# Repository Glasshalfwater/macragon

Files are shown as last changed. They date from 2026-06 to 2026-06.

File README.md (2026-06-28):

# Macragon

### Hexagonal macropad powered by a Waveshare 2040-zero with multiple keyboard layers, USB-C connectivity, RGB LEDs, and planned voice keyboard functionality.

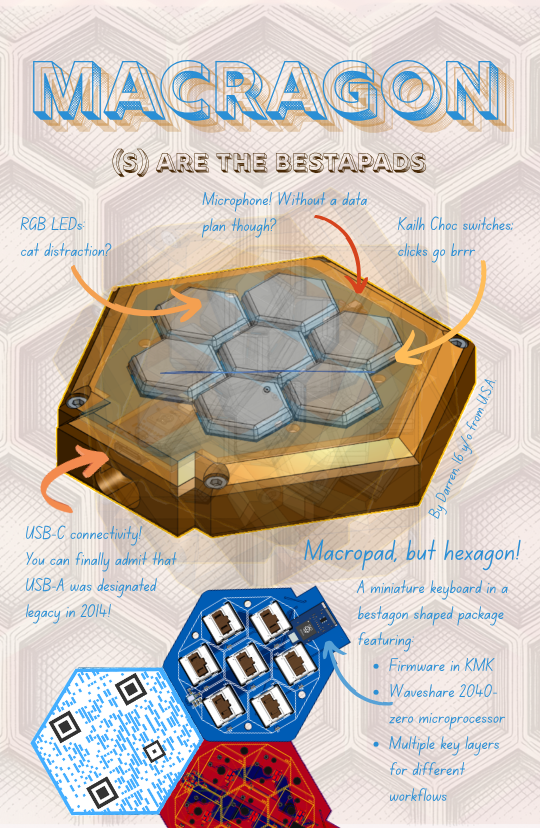
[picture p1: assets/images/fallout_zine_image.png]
zine poster


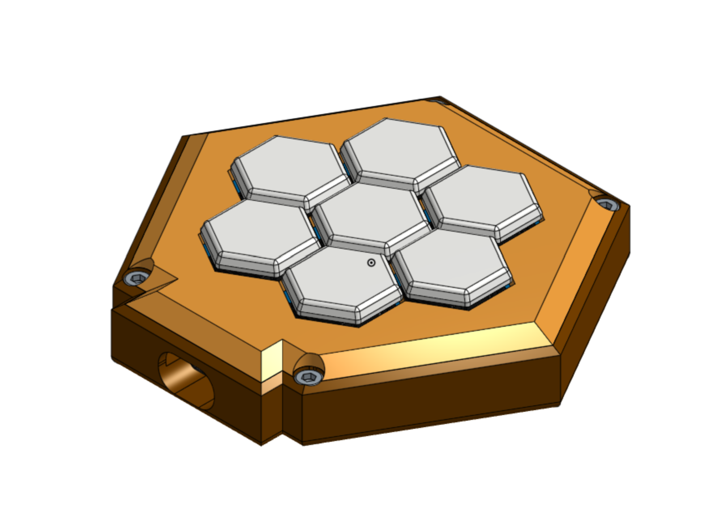
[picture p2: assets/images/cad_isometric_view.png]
Onshape link (https://cvilleschools.onshape.com/documents/f18c9192e8883840eb23ee3e/w/cfee4e89906b8c2d7cd90130/e/c8d4c75ffcaf924e3f809773)


## Origins:
To be honest, my main motivation behind this project is mostly laziness :>. Long story short, my engineering class's keyboards are a bit annoying. To use them properly, one has to actually sit in their chair very close to one's respective desk (it's more tiring than it sounds after an hour and a half). The chair arms are too far apart to support the keyboard away from the desk, and the rubber pads on the bottom of the keyboard mean that dust and debris will collect on your pants if the keyboard is in your lap. So, what I wanted to do is to have a little mic I could carry around that functioned as a voice keyboard, so I could actually slouch in my chair comfortably at a distance. That, combined with me seeing a lot of other Hackclub projects being macropads, meant I decided to make a fusion between the two. Ideally, the goal was to learn how to read and make schematics, PCB design, and improve my coding skills. The (farfetched) dream would be to have a voice keyboard that could recognize CAD commands while also having buttons for manual functions. Unfortunately, implementing a voice keyboard that plugs in as a USB audio device was harder than I expected in Python (I had decided to use KMK instead of QMK), compounded by my lack of experience in Python and with USB audio communication. As such, it has been left off until v2 of the macragon. However, the macropad keys still work, and as a bonus they have RGB LEDs. Additionally, the hardware for the microphone is on the PCB, and QMK supports the microprocessor, etc., so adding a voice keyboard will simply be a firmware update.

Another segment of motivation is just my fingers getting mad at me after I'd been creating hexagons and other repetitive tasks in Onshape without convienient keybinds for two hours a day for a week. (Yeah, I probably should have just unbound some other keybind I wasn't using, but macropads are cooler.)

On the other hand, choosing the shape of my macropad was [easy](https://www.youtube.com/watch?v=thOifuHs6eY).

## Wiring Schematic 
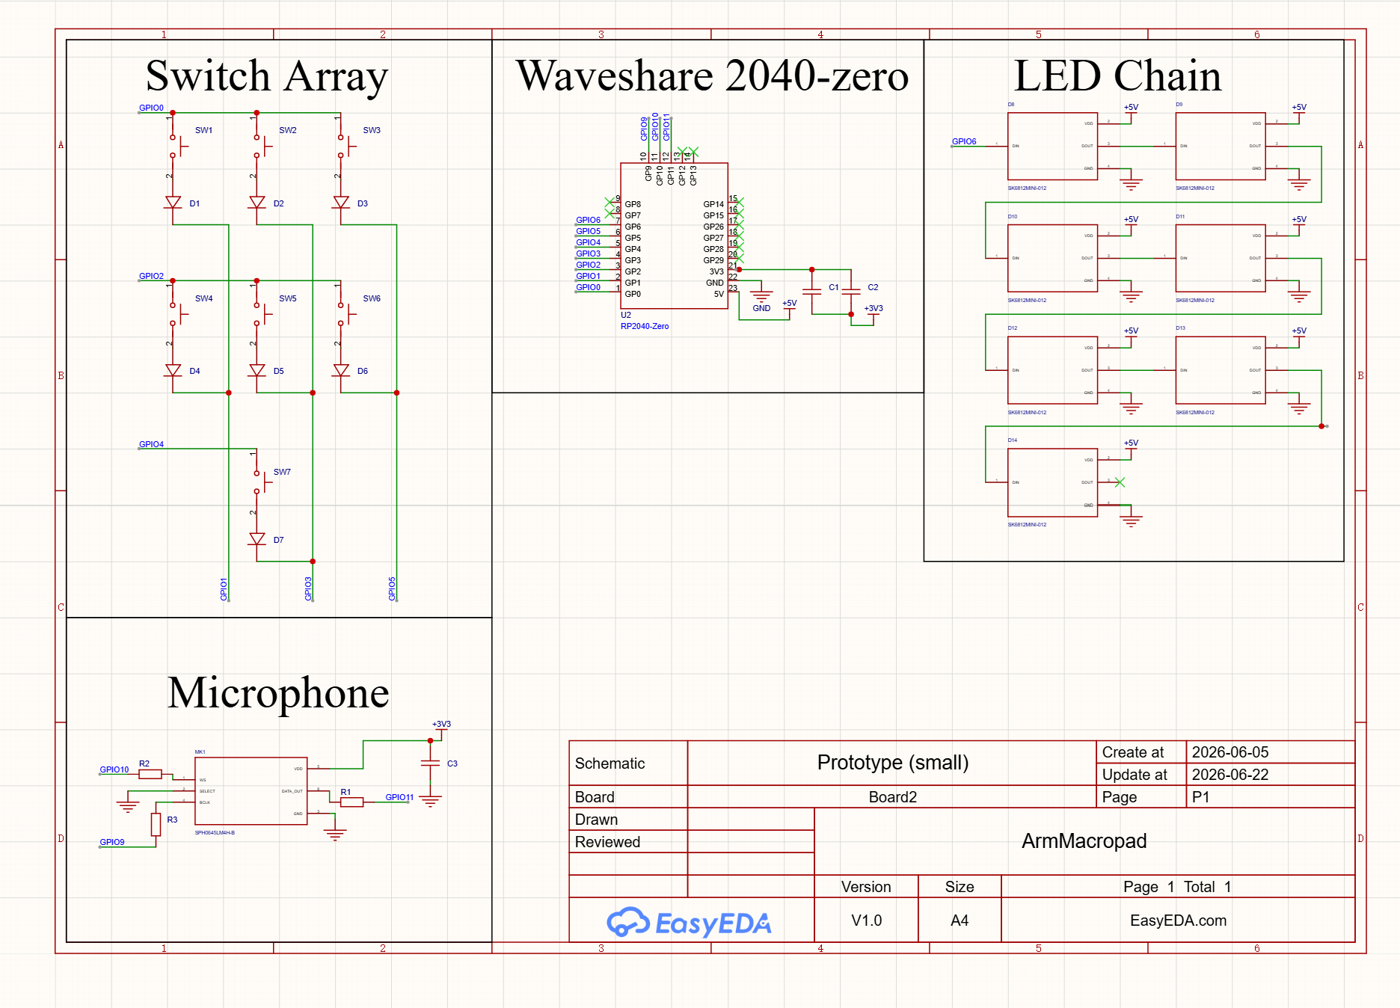
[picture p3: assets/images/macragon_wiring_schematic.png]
macragon wiring schematic


## PCB 
Top layer:
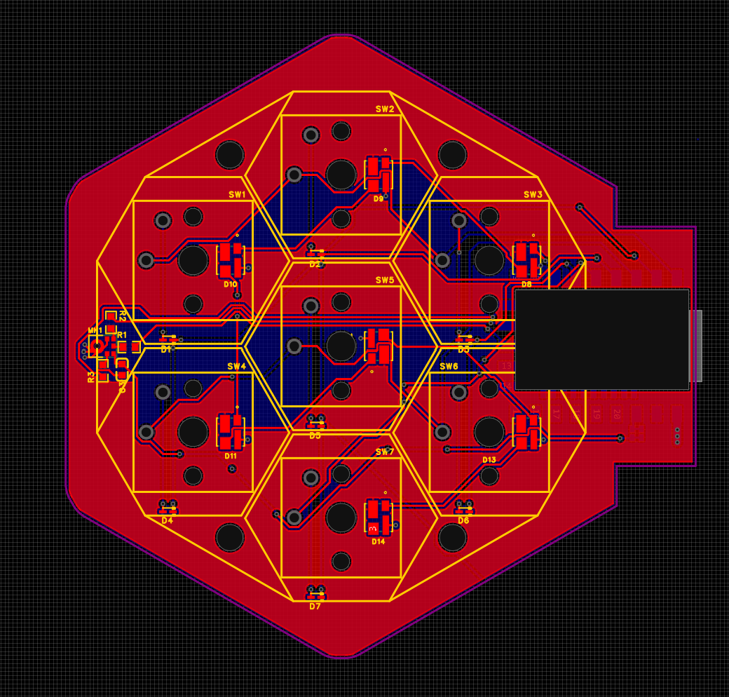
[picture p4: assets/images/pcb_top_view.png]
macragon pcb top view


Bottom layer:
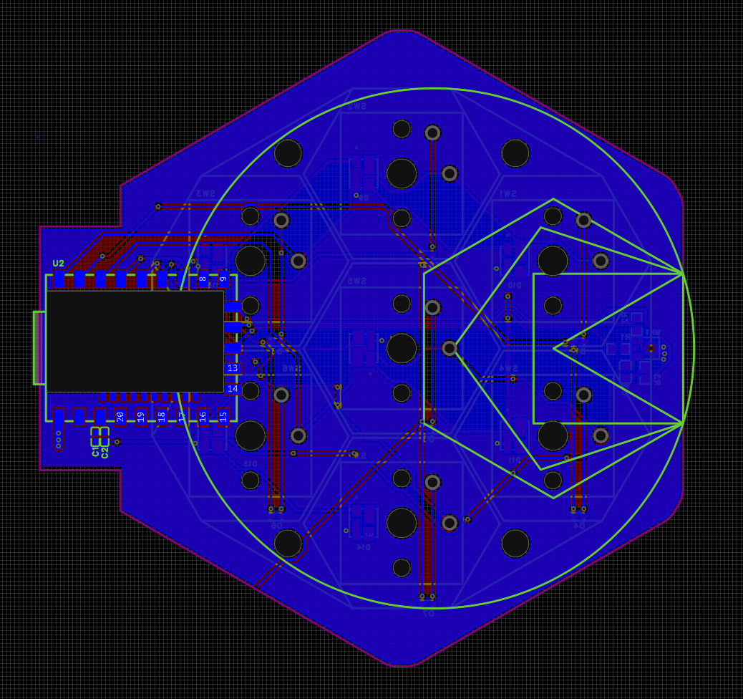
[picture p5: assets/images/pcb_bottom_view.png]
macragon pcb bottom view


## CAD
### Done in Onshape
[Onshape Document Link](https://cvilleschools.onshape.com/documents/f18c9192e8883840eb23ee3e/w/cfee4e89906b8c2d7cd90130/e/c8d4c75ffcaf924e3f809773)

Isometric:
Macragon assembly isometric view

Top:
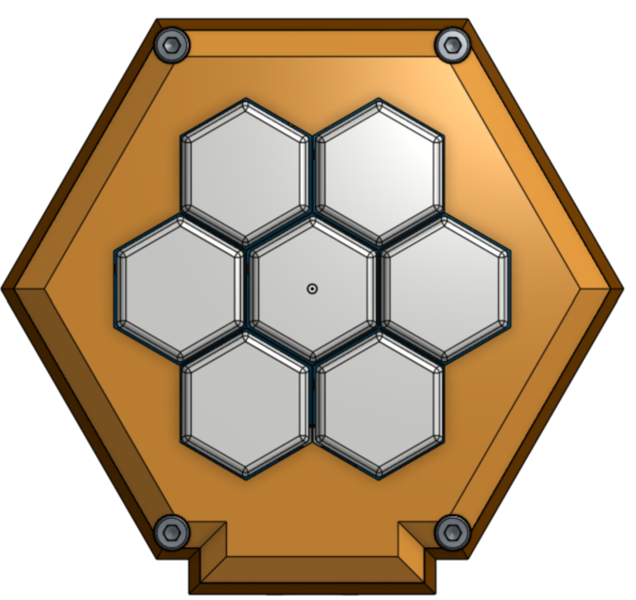
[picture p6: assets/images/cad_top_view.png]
Macragon assembly top view


Bottom:
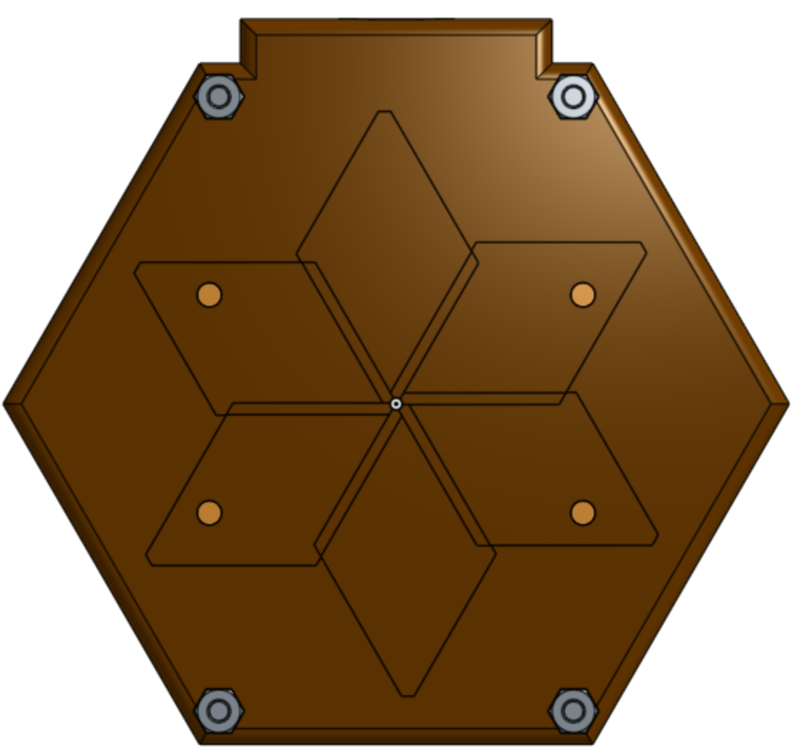
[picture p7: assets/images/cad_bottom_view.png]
Macragon assembly bottom view


Side:
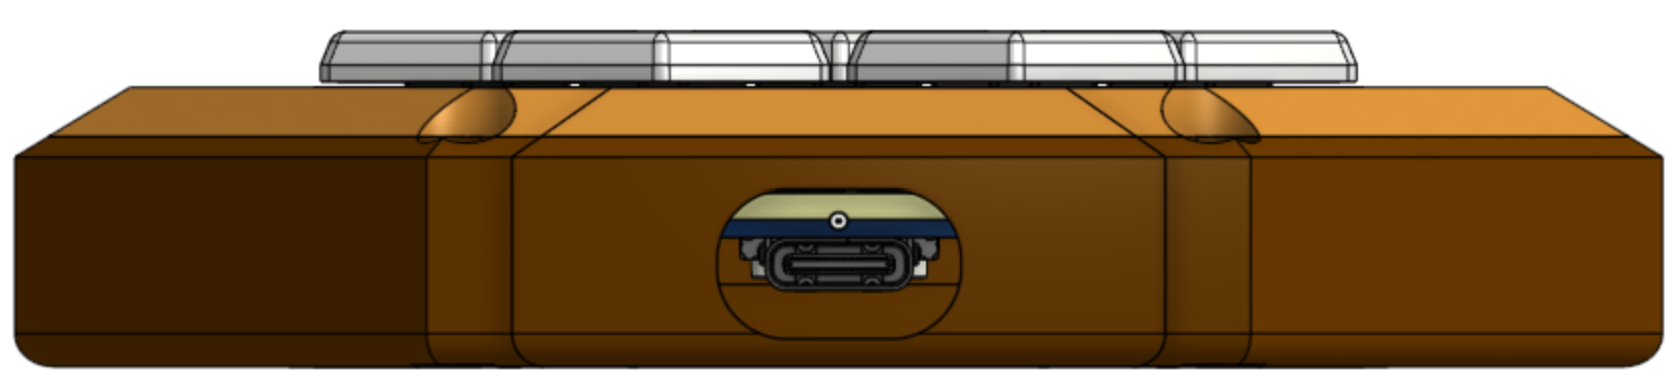
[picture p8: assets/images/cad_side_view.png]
Macragon assembly side view

(how low can it go?)

## PCB Order
From JLCPCB:
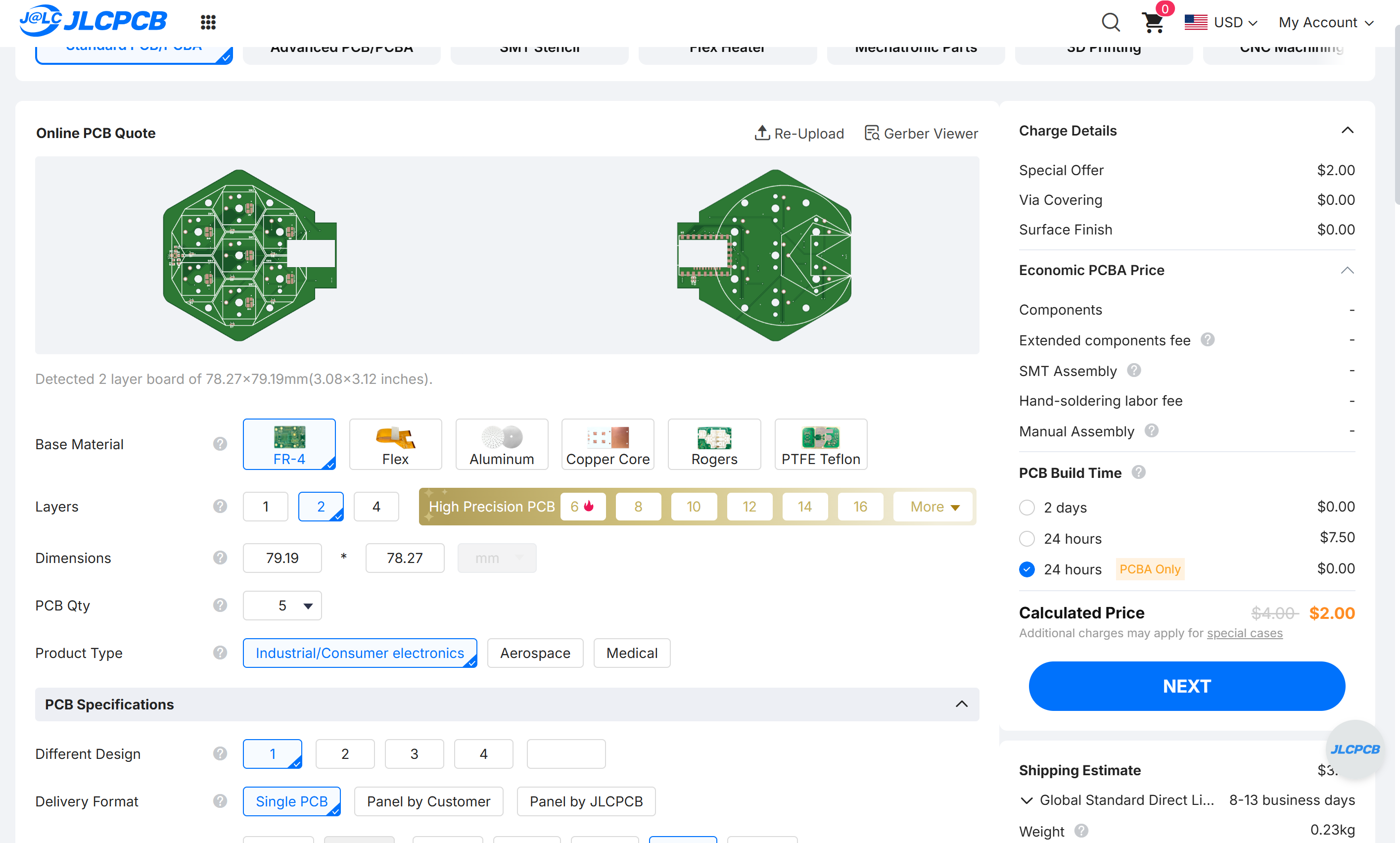
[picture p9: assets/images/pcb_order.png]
JLCPCB Order


## BOM
|Quantity|Designator |Price |Footprint |Value/Purpose |Manufacturer |Supplier Part |Supplier |Link |FIELD10 |
|---|---|---|---|---|---|---|---|---|---|
|1 |	 Decoupling Capacitor |	$1.09/50 |	C0402 |	1uF |	SAMSUNG(三星) |	C307413 |	LCSC |	https://www.lcsc.com/product-detail/C307413.html?s_z=n_q_C307413&globalKeyword=C307413 | |
|1 |	 Decoupling Capacitor |	$0.64/50 |	C0402 |	100nF |	muRata(村田) |	C77020 |	LCSC |	https://www.lcsc.com/product-detail/C77020.html?s_z=n_q_C77020&globalKeyword=C77020 | |
|1 |	 Decoupling Capacitor |	$1.49/50 |	C0603 |	1uF |	SAMSUNG(三星) |	C15849 |	LCSC |	https://www.lcsc.com/product-detail/C15849.html?s_z=n_q_C15849&globalKeyword=C15849 | |
|7 |	 Keyboard Matrix Diodes |	$0.43/10 |	SOD-523_L1.2-W0.8-LS1.6-RD  |	1N4148WT/preventing ghosting |	onsemi(安森美) |	C232841 |	LCSC |	https://www.lcsc.com/product-detail/C232841.html?s_z=n_q_C232841&globalKeyword=C232841 | |
|7 | 	 RGB LEDs |	$0.97/7 |	LED_SK6812MINI-012 |	SK6812MINI-012/lighting |	OPSCO Optoelectronics|	C2886570 |	LCSC |	https://www.lcsc.com/product-detail/C2886570.html?s_z=n_q_C2886570&globalKeyword=C2886570 | |
|1 | 	 Microphone |	$3.15/1 |	 MIC_SPH0645LM4H-B |	SPH0645LM4H-B/Audio input |	Knowles |	C19190864 | 	LCSC |	https://www.lcsc.com/product-detail/C19190864.html?s_z=n_q_C19190864&globalKeyword=C19190864 | |
|3 | 	 Microphone Resistors |	$0.19/100 |	R0603 |	51Ω/Controlling current to mic | 	YAGEO(国巨) |	C114628 |	LCSC |	https://www.lcsc.com/product-detail/C114628.html?s_z=n_q_C114628&globalKeyword=C114628 | |
|7 |	 Kailh Choc v1 Switches |	$8.31/10 |	KEY-TH_CPG135001D0X |	CPG135001D02/Obtaining button inputs |	Kailh(凯华) |	N/A |	Amazon |	https://www.lcsc.com/product-detail/C400230.html?s_z=n_q_C400230&globalKeyword=C400230 | |
|7 |	 Hexagon Keycaps |	$6/10 |	N/A |	s-ol hex keycaps |	fkcaps |	Hex Keycaps |	Little Keyboards |	https://fkcaps.com/keycaps/hex |	 |
|1 |	 RP2040-zero |	$6.07/1 |	 COMM-SMD_RP2040-ZERO|	Microprocessor to run KMK |	Waveshare(微雪电子) |	C5350143 |	LCSC |	https://www.lcsc.com/product-detail/C19190864.html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 | |
|1 |	 USB-C to USB-A Cable |	Owned |	N/A |	Computer to macropad connection |	Amazon Basics |	N/A |	amazon.com |	https://www.amazon.com/Amazon-Basics-Charger-480Mbps-Certified/dp/B01GGKZ1VA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 | |
|1 | 	Soldering Iron | Free Access | N/A | Attaching components to PCB |	pine64 |	Pinecil v2 |	School | https://pine64.com/product/pinecil-smart-mini-portable-soldering-iron/ | |
|1 |	 Solder (lead free and flux core) | Free Access | N/A | Soldering | ZSHX | N/A | School | https://www.amazon.com/ZSHX-Solder-solder-electrical-soldering/dp/B07QZX9LG2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| |
|1 | ABS Filament (~0.027382335 kg) | $25/1kg (Free Access)| N/A | For printing macropad case | Elegoo | N/A | amazon.com | https://www.amazon.com/ELEGOO-Filament-Resistant-Toughness-Resistance/dp/B0F37VY5VZ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 | |
|8 |	 M3 Socket Head Screws (14 mm and 20 mm)|	Owned |	N/A |	Holding the case together and fastening PCB to case|	McMaster-Carr |	91290A119 and 91290A123| 	McMaster-Carr |	https://www.mcmaster.com/products/screws/socket-head-screws-2~/steel-socket-head-screws~~/ | |
|8 |	 M3 Hex Nuts |	Owned |	N/A |	Holding screws in place |	McMaster-Carr |		94150A325 |	McMaster-Carr |	https://www.mcmaster.com/products/nuts/hex-nuts-5~/thread-size~m3/hex-nuts-5~material~stainless-steel-2/ | |
|1 | 	 PCB + Stencil + Shipping |	$25.12 |	N/A |	 N/A |	 JLCPCB |	 N/A |	 JLCPCB |	 https://cart.jlcpcb.com/quote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 | |
|1 |	 Total Cost |	$53.46 |	 N/A |	Building Cool Stuff |	 N/A |	 N/A |	 My Wallet|	N/A | |

## Challenges
I am not really familiar with Python beyond basic use (most of my experience is in C, but it's been a while), so acquanting myself with a new programming language was a bit of a challenge. Luckily, KMK has pretty good documentation on its setup all of its macros, keybinds, and lighting commands, and high-level firmware isn't that complex. (Trying to unlearn putting a semicolon after each line was probably harder.) Before Fallout, I wasn't really familiar with wiring schematics and the related symbols, so learning that was also a challenge. This is also like my 4th ever PCB (I did my first last month), (the first one was literally a 2 pin header, then a really simple barometer, and then the USB-Hub guided project), and my first one where I had to make the wiring schematic entirely by myself. (So, you know, please don't flame me over its design?) Overall, it was interesting looking up hardware to see what would be a best fit, along with considering whether parts could handle the necessary requirements. This is also my first project reading through data sheet specs and wiring schematics (well, and actually understanding them).

For finding hardware, on my previous projects in my school would simply only allow me to use certain components, so there wasn't really a large amount of choice. After looking at other macropads and Reddit, the Cherry MX switch line seemed quite popular, however the hexagonal keycaps I had found only fit Kailh Choc v1 switch stem patterns. I originally went with Choc Browns, however the lowprobkb Ambient switches seemed a better fit in terms of actuation force. Unfortunately, the Ambient switches would have muted the effects of the RGB LEDs, so I reverted back to the Choc Browns. Forums such as Adafruit and Stack Overflow proved useful along with Google for finding commonly used LEDs and microphones. From these, I narrowed down options further based on what KMK firmware was compatible with and had a decent footprint. For other components, I mostly utilized LCSC's filters and selected an option that was rated for higher than necessary. (Of course, with a minimum purchase amount less than ten thousand.)

Of course, along the way I made a good chunk of beginner mistakes. Originally, I had planned to put the microprocessor at the center of the PCB on the bottom side. However, I failed to notice that the footprint required a slot and only discovered this after finishing wiring the traces. Thus, in order to avoid the slot conflicting with the switch on top, I had to enlarge the board slightly, move the RP-2040 zero to the side, and and rewire the entire board. Somehow I managed to fail to be concerned about my SMD diodes having through bore footprints, until I was almost putting images into my README (another rewire, yippee). I also didn't know that most macropads utilized diodes to ensure power flowed from the column to the row, and instead did the opposite. I only found out after finishing the PCB and writing the firmware that KMK had features that only worked for column to row keyboard matrices.

I suppose the moral of my long winded list of failures is, it's natural to make mistakes, so don't fret about it. Even when you might have messed up your entire project and have to redo it, or forgotten a crucial component days before you have to show it off, it's okay. Learn from it, gain more experience, it won't matter if the world ends on the 7th anyway.

## Setup 
In the event you are building this yourself, the [necessary materials](/BOM.csv), the required files to [order and assemble the PCB](/hardware), and the files to [3D print the case](/hardware) are can be found above. The locations for where to solder components can be viewed by opening [the .epro file](/hardware/Macragon.epro2) for the PCB, and a [guide on soldering SMD components](https://www.youtube.com/watch?v=GAjuZoyAhgI&themeRefresh=1) is linked in the credits below. After you have acquired and assembled the hardware necessary, plug the Waveshare 2040-zero into your computer via a USB-C cable capable of data transfer, and follow the instructions on the [Waveshare Wiki](https://www.waveshare.com/wiki/RP2040-Zero) to place the board in bootloader mode. Afterwards, the board should show up in your File Explorer (or equivalent) as a removable USB device, upon which you should to place the [.uf2 CircuitPython firmware file](firmware\adafruit-circuitpython-waveshare_rp2040_zero-en_US-10.2.1.uf2) into the USB drive. 

In order to install [KMK](https://github.com/KMKfw/kmk_firmware/blob/main/docs/en/Getting_Started.md) (circuitpython fork and keyboard firmware) onto the board, [download the latest version of KMK](https://github.com/KMKfw/kmk_firmware/archive/refs/heads/main.zip) from the main branch. Then, extract the kmk_firmware-main folder and copy the kmk folder within on to the Waveshare board while the board is in bootloader mode (will require a new bootloader session), where it should show up as a CIRCUITPY drive. Replace the board.py/code.py file with the [main.py](firmware\src\main.py) file located in the src directory of this repository. The main.py file contains the keymap and two layers. Of course, if you want to make your own key layers, animations, and macros/, etc., just edit the main.py file (links to KMK docs on a [list of keycodes](https://github.com/KMKfw/kmk_firmware/blob/main/docs/en/keycodes.md), [layers](https://github.com/KMKfw/kmk_firmware/blob/main/docs/en/layers.md), and [RGB LED input/outputs](https://github.com/KMKfw/kmk_firmware/blob/main/docs/en/rgb.md) and [macros](https://github.com/KMKfw/kmk_firmware/blob/main/docs/en/layers.md)). In addition, you will need to download and then place the appropriate version of the [board module](https://circuitpython.org/libraries) from the libraries bundle (that matches w/ your CircuitPython) into the CIRCUITPY drive. After that, take the board out of bootloader and you should be good to go!

Google is probably your friend (just don't read the EULA or privacy policy too closely), so if something unexpected happens, look it up! There is almost certainly info and tutorials online about how to fix it and those who have experienced it before (unless you happen to be one Newton Pulsifer, in which case just try to break the firmware I guess?). Of course, documentation relevant to setting up various aspects of the firmware is also linked in the above paragraphs and in the Useful Links section of this README.

## Useful Links
[KMK Firmware Repository](https://github.com/KMKfw/kmk_firmware/tree/main)

[CircuitPython Library Bundle Download](https://circuitpython.org/libraries)

[Waveshare Wiki](https://www.waveshare.com/wiki/RP2040-Zero)

[Soldering Youtube Tutorial](https://www.youtube.com/watch?v=GAjuZoyAhgI&themeRefresh=1)

If you prefer, shorter, shallower videos also can be found. Alternatively, you can skip around to the parts you need.

## Credits

### CAD completed in Onshape

### PCB design completed in EasyEDA Pro

### Zine designed in Canva

### .csv to BOM conversion done with [convertcsv.com](convertcsv.com)

### Sources of knowledge and inspiration (for design, layout, and also just because I didn't know how to organize a repo well):
[NotARoomba's Cyberboard v2](https://blueprint.hackclub.com/projects/491)

Hackclub Fallout's pages on [good projects](https://fallout.hackclub.com/docs/project-resources/good-fallout-projects) and [zines](https://fallout.hackclub.com/docs/requirements/fallout-zine)

[Hackclub Magazine](https://magazine.hackclub.com/)

[s-ol's 0xC macropad](https://hw.s-ol.nu/0xC.pad/)
(how I found existing hexagonal keycaps)

[KMK Firmware Documentation](https://github.com/KMKfw/kmk_firmware)
Note: KMK is under the GNU General Public Licence Version 3 (GPLv3)

[Github's Basic Markdown Documentation](https://docs.github.com/en/get-started/writing-on-github/getting-started-with-writing-and-formatting-on-github/basic-writing-and-formatting-syntax)

## Licenses:
### NOTE: No further info below licenses

Code belonging to this project is licensed under the MIT license, as per the [LICENSE](/LICENSE) file. Licenses for 3rd party libraries are below:

Adafruit libraries are licensed under the MIT license:
'''
The MIT License (MIT)

Copyright (c) 2013-2025 Damien P. George

Permission is hereby granted, free of charge, to any person obtaining a copy
of this software and associated documentation files (the "Software"), to deal
in the Software without restriction, including without limitation the rights
to use, copy, modify, merge, publish, distribute, sublicense, and/or sell
copies of the Software, and to permit persons to whom the Software is
furnished to do so, subject to the following conditions:

The above copyright notice and this permission notice shall be included in
all copies or substantial portions of the Software.

THE SOFTWARE IS PROVIDED "AS IS", WITHOUT WARRANTY OF ANY KIND, EXPRESS OR
IMPLIED, INCLUDING BUT NOT LIMITED TO THE WARRANTIES OF MERCHANTABILITY,
FITNESS FOR A PARTICULAR PURPOSE AND NONINFRINGEMENT. IN NO EVENT SHALL THE
AUTHORS OR COPYRIGHT HOLDERS BE LIABLE FOR ANY CLAIM, DAMAGES OR OTHER
LIABILITY, WHETHER IN AN ACTION OF CONTRACT, TORT OR OTHERWISE, ARISING FROM,
OUT OF OR IN CONNECTION WITH THE SOFTWARE OR THE USE OR OTHER DEALINGS IN
THE SOFTWARE.

--------------------------------------------------------------------------------

Unless specified otherwise (see below), the above license and copyright applies
to all files derived from MicroPython in this repository.

Individual files may include additional copyright holders and specify other licenses.
See the comments and SPDX headers.
'''

KMK is licensed under the GNU General Public License Version 3 (GPLv3):
'''
GNU GENERAL PUBLIC LICENSE
Version 3, 29 June 2007

Copyright (C) 2007 Free Software Foundation, Inc. https://fsf.org/

Everyone is permitted to copy and distribute verbatim copies of this license document, but changing it is not allowed.

Preamble
The GNU General Public License is a free, copyleft license for software and other kinds of works.

The licenses for most software and other practical works are designed to take away your freedom to share and change the works. By contrast, the GNU General Public License is intended to guarantee your freedom to share and change all versions of a program--to make sure it remains free software for all its users. We, the Free Software Foundation, use the GNU General Public License for most of our software; it applies also to any other work released this way by its authors. You can apply it to your programs, too.

When we speak of free software, we are referring to freedom, not price. Our General Public Licenses are designed to make sure that you have the freedom to distribute copies of free software (and charge for them if you wish), that you receive source code or can get it if you want it, that you can change the software or use pieces of it in new free programs, and that you know you can do these things.

To protect your rights, we need to prevent others from denying you these rights or asking you to surrender the rights. Therefore, you have certain responsibilities if you distribute copies of the software, or if you modify it: responsibilities to respect the freedom of others.

For example, if you distribute copies of such a program, whether gratis or for a fee, you must pass on to the recipients the same freedoms that you received. You must make sure that they, too, receive or can get the source code. And you must show them these terms so they know their rights.

Developers that use the GNU GPL protect your rights with two steps: (1) assert copyright on the software, and (2) offer you this License giving you legal permission to copy, distribute and/or modify it.

For the developers' and authors' protection, the GPL clearly explains that there is no warranty for this free software. For both users' and authors' sake, the GPL requires that modified versions be marked as changed, so that their problems will not be attributed erroneously to authors of previous versions.

Some devices are designed to deny users access to install or run modified versions of the software inside them, although the manufacturer can do so. This is fundamentally incompatible with the aim of protecting users' freedom to change the software. The systematic pattern of such abuse occurs in the area of products for individuals to use, which is precisely where it is most unacceptable. Therefore, we have designed this version of the GPL to prohibit the practice for those products. If such problems arise substantially in other domains, we stand ready to extend this provision to those domains in future versions of the GPL, as needed to protect the freedom of users.

Finally, every program is threatened constantly by software patents. States should not allow patents to restrict development and use of software on general-purpose computers, but in those that do, we wish to avoid the special danger that patents applied to a free program could make it effectively proprietary. To prevent this, the GPL assures that patents cannot be used to render the program non-free.

The precise terms and conditions for copying, distribution and modification follow.

TERMS AND CONDITIONS
0. Definitions.
"This License" refers to version 3 of the GNU General Public License.

"Copyright" also means copyright-like laws that apply to other kinds of works, such as semiconductor masks.

"The Program" refers to any copyrightable work licensed under this License. Each licensee is addressed as "you". "Licensees" and "recipients" may be individuals or organizations.

To "modify" a work means to copy from or adapt all or part of the work in a fashion requiring copyright permission, other than the making of an exact copy. The resulting work is called a "modified version" of the earlier work or a work "based on" the earlier work.

A "covered work" means either the unmodified Program or a work based on the Program.

To "propagate" a work means to do anything with it that, without permission, would make you directly or secondarily liable for infringement under applicable copyright law, except executing it on a computer or modifying a private copy. Propagation includes copying, distribution (with or without modification), making available to the public, and in some countries other activities as well.

To "convey" a work means any kind of propagation that enables other parties to make or receive copies. Mere interaction with a user through a computer network, with no transfer of a copy, is not conveying.

An interactive user interface displays "Appropriate Legal Notices" to the extent that it includes a convenient and prominently visible feature that (1) displays an appropriate copyright notice, and (2) tells the user that there is no warranty for the work (except to the extent that warranties are provided), that licensees may convey the work under this License, and how to view a copy of this License. If the interface presents a list of user commands or options, such as a menu, a prominent item in the list meets this criterion.

1. Source Code.
The "source code" for a work means the preferred form of the work for making modifications to it. "Object code" means any non-source form of a work.

A "Standard Interface" means an interface that either is an official standard defined by a recognized standards body, or, in the case of interfaces specified for a particular programming language, one that is widely used among developers working in that language.

The "System Libraries" of an executable work include anything, other than the work as a whole, that (a) is included in the normal form of packaging a Major Component, but which is not part of that Major Component, and (b) serves only to enable use of the work with that Major Component, or to implement a Standard Interface for which an implementation is available to the public in source code form. A "Major Component", in this context, means a major essential component (kernel, window system, and so on) of the specific operating system (if any) on which the executable work runs, or a compiler used to produce the work, or an object code interpreter used to run it.

The "Corresponding Source" for a work in object code form means all the source code needed to generate, install, and (for an executable work) run the object code and to modify the work, including scripts to control those activities. However, it does not include the work's System Libraries, or general-purpose tools or generally available free programs which are used unmodified in performing those activities but which are not part of the work. For example, Corresponding Source includes interface definition files associated with source files for the work, and the source code for shared libraries and dynamically linked subprograms that the work is specifically designed to require, such as by intimate data communication or control flow between those subprograms and other parts of the work.

The Corresponding Source need not include anything that users can regenerate automatically from other parts of the Corresponding Source.

The Corresponding Source for a work in source code form is that same work.

2. Basic Permissions.
All rights granted under this License are granted for the term of copyright on the Program, and are irrevocable provided the stated conditions are met. This License explicitly affirms your unlimited permission to run the unmodified Program. The output from running a covered work is covered by this License only if the output, given its content, constitutes a covered work. This License acknowledges your rights of fair use or other equivalent, as provided by copyright law.

You may make, run and propagate covered works that you do not convey, without conditions so long as your license otherwise remains in force. You may convey covered works to others for the sole purpose of having them make modifications exclusively for you, or provide you with facilities for running those works, provided that you comply with the terms of this License in conveying all material for which you do not control copyright. Those thus making or running the covered works for you must do so exclusively on your behalf, under your direction and control, on terms that prohibit them from making any copies of your copyrighted material outside their relationship with you.

Conveying under any other circumstances is permitted solely under the conditions stated below. Sublicensing is not allowed; section 10 makes it unnecessary.

3. Protecting Users' Legal Rights From Anti-Circumvention Law.
No covered work shall be deemed part of an effective technological measure under any applicable law fulfilling obligations under article 11 of the WIPO copyright treaty adopted on 20 December 1996, or similar laws prohibiting or restricting circumvention of such measures.

When you convey a covered work, you waive any legal power to forbid circumvention of technological measures to the extent such circumvention is effected by exercising rights under this License with respect to the covered work, and you disclaim any intention to limit operation or modification of the work as a means of enforcing, against the work's users, your or third parties' legal rights to forbid circumvention of technological measures.

4. Conveying Verbatim Copies.
You may convey verbatim copies of the Program's source code as you receive it, in any medium, provided that you conspicuously and appropriately publish on each copy an appropriate copyright notice; keep intact all notices stating that this License and any non-permissive terms added in accord with section 7 apply to the code; keep intact all notices of the absence of any warranty; and give all recipients a copy of this License along with the Program.

You may charge any price or no price for each copy that you convey, and you may offer support or warranty protection for a fee.

5. Conveying Modified Source Versions.
You may convey a work based on the Program, or the modifications to produce it from the Program, in the form of source code under the terms of section 4, provided that you also meet all of these conditions:

a) The work must carry prominent notices stating that you modified it, and giving a relevant date.
b) The work must carry prominent notices stating that it is released under this License and any conditions added under section 7. This requirement modifies the requirement in section 4 to "keep intact all notices".
c) You must license the entire work, as a whole, under this License to anyone who comes into possession of a copy. This License will therefore apply, along with any applicable section 7 additional terms, to the whole of the work, and all its parts, regardless of how they are packaged. This License gives no permission to license the work in any other way, but it does not invalidate such permission if you have separately received it.
d) If the work has interactive user interfaces, each must display Appropriate Legal Notices; however, if the Program has interactive interfaces that do not display Appropriate Legal Notices, your work need not make them do so.
A compilation of a covered work with other separate and independent works, which are not by their nature extensions of the covered work, and which are not combined with it such as to form a larger program, in or on a volume of a storage or distribution medium, is called an "aggregate" if the compilation and its resulting copyright are not used to limit the access or legal rights of the compilation's users beyond what the individual works permit. Inclusion of a covered work in an aggregate does not cause this License to apply to the other parts of the aggregate.

6. Conveying Non-Source Forms.
You may convey a covered work in object code form under the terms of sections 4 and 5, provided that you also convey the machine-readable Corresponding Source under the terms of this License, in one of these ways:

a) Convey the object code in, or embodied in, a physical product (including a physical distribution medium), accompanied by the Corresponding Source fixed on a durable physical medium customarily used for software interchange.
b) Convey the object code in, or embodied in, a physical product (including a physical distribution medium), accompanied by a written offer, valid for at least three years and valid for as long as you offer spare parts or customer support for that product model, to give anyone who possesses the object code either (1) a copy of the Corresponding Source for all the software in the product that is covered by this License, on a durable physical medium customarily used for software interchange, for a price no more than your reasonable cost of physically performing this conveying of source, or (2) access to copy the Corresponding Source from a network server at no charge.
c) Convey individual copies of the object code with a copy of the written offer to provide the Corresponding Source. This alternative is allowed only occasionally and noncommercially, and only if you received the object code with such an offer, in accord with subsection 6b.
d) Convey the object code by offering access from a designated place (gratis or for a charge), and offer equivalent access to the Corresponding Source in the same way through the same place at no further charge. You need not require recipients to copy the Corresponding Source along with the object code. If the place to copy the object code is a network server, the Corresponding Source may be on a different server (operated by you or a third party) that supports equivalent copying facilities, provided you maintain clear directions next to the object code saying where to find the Corresponding Source. Regardless of what server hosts the Corresponding Source, you remain obligated to ensure that it is available for as long as needed to satisfy these requirements.
e) Convey the object code using peer-to-peer transmission, provided you inform other peers where the object code and Corresponding Source of the work are being offered to the general public at no charge under subsection 6d.
A separable portion of the object code, whose source code is excluded from the Corresponding Source as a System Library, need not be included in conveying the object code work.

A "User Product" is either (1) a "consumer product", which means any tangible personal property which is normally used for personal, family, or household purposes, or (2) anything designed or sold for incorporation into a dwelling. In determining whether a product is a consumer product, doubtful cases shall be resolved in favor of coverage. For a particular product received by a particular user, "normally used" refers to a typical or common use of that class of product, regardless of the status of the particular user or of the way in which the particular user actually uses, or expects or is expected to use, the product. A product is a consumer product regardless of whether the product has substantial commercial, industrial or non-consumer uses, unless such uses represent the only significant mode of use of the product.

"Installation Information" for a User Product means any methods, procedures, authorization keys, or other information required to install and execute modified versions of a covered work in that User Product from a modified version of its Corresponding Source. The information must suffice to ensure that the continued functioning of the modified object code is in no case prevented or interfered with solely because modification has been made.

If you convey an object code work under this section in, or with, or specifically for use in, a User Product, and the conveying occurs as part of a transaction in which the right of possession and use of the User Product is transferred to the recipient in perpetuity or for a fixed term (regardless of how the transaction is characterized), the Corresponding Source conveyed under this section must be accompanied by the Installation Information. But this requirement does not apply if neither you nor any third party retains the ability to install modified object code on the User Product (for example, the work has been installed in ROM).

The requirement to provide Installation Information does not include a requirement to continue to provide support service, warranty, or updates for a work that has been modified or installed by the recipient, or for the User Product in which it has been modified or installed. Access to a network may be denied when the modification itself materially and adversely affects the operation of the network or violates the rules and protocols for communication across the network.

Corresponding Source conveyed, and Installation Information provided, in accord with this section must be in a format that is publicly documented (and with an implementation available to the public in source code form), and must require no special password or key for unpacking, reading or copying.

7. Additional Terms.
"Additional permissions" are terms that supplement the terms of this License by making exceptions from one or more of its conditions. Additional permissions that are applicable to the entire Program shall be treated as though they were included in this License, to the extent that they are valid under applicable law. If additional permissions apply only to part of the Program, that part may be used separately under those permissions, but the entire Program remains governed by this License without regard to the additional permissions.

When you convey a copy of a covered work, you may at your option remove any additional permissions from that copy, or from any part of it. (Additional permissions may be written to require their own removal in certain cases when you modify the work.) You may place additional permissions on material, added by you to a covered work, for which you have or can give appropriate copyright permission.

Notwithstanding any other provision of this License, for material you add to a covered work, you may (if authorized by the copyright holders of that material) supplement the terms of this License with terms:

a) Disclaiming warranty or limiting liability differently from the terms of sections 15 and 16 of this License; or
b) Requiring preservation of specified reasonable legal notices or author attributions in that material or in the Appropriate Legal Notices displayed by works containing it; or
c) Prohibiting misrepresentation of the origin of that material, or requiring that modified versions of such material be marked in reasonable ways as different from the original version; or
d) Limiting the use for publicity purposes of names of licensors or authors of the material; or
e) Declining to grant rights under trademark law for use of some trade names, trademarks, or service marks; or
f) Requiring indemnification of licensors and authors of that material by anyone who conveys the material (or modified versions of it) with contractual assumptions of liability to the recipient, for any liability that these contractual assumptions directly impose on those licensors and authors.
All other non-permissive additional terms are considered "further restrictions" within the meaning of section 10. If the Program as you received it, or any part of it, contains a notice stating that it is governed by this License along with a term that is a further restriction, you may remove that term. If a license document contains a further restriction but permits relicensing or conveying under this License, you may add to a covered work material governed by the terms of that license document, provided that the further restriction does not survive such relicensing or conveying.

If you add terms to a covered work in accord with this section, you must place, in the relevant source files, a statement of the additional terms that apply to those files, or a notice indicating where to find the applicable terms.

Additional terms, permissive or non-permissive, may be stated in the form of a separately written license, or stated as exceptions; the above requirements apply either way.

8. Termination.
You may not propagate or modify a covered work except as expressly provided under this License. Any attempt otherwise to propagate or modify it is void, and will automatically terminate your rights under this License (including any patent licenses granted under the third paragraph of section 11).

However, if you cease all violation of this License, then your license from a particular copyright holder is reinstated (a) provisionally, unless and until the copyright holder explicitly and finally terminates your license, and (b) permanently, if the copyright holder fails to notify you of the violation by some reasonable means prior to 60 days after the cessation.

Moreover, your license from a particular copyright holder is reinstated permanently if the copyright holder notifies you of the violation by some reasonable means, this is the first time you have received notice of violation of this License (for any work) from that copyright holder, and you cure the violation prior to 30 days after your receipt of the notice.

Termination of your rights under this section does not terminate the licenses of parties who have received copies or rights from you under this License. If your rights have been terminated and not permanently reinstated, you do not qualify to receive new licenses for the same material under section 10.

9. Acceptance Not Required for Having Copies.
You are not required to accept this License in order to receive or run a copy of the Program. Ancillary propagation of a covered work occurring solely as a consequence of using peer-to-peer transmission to receive a copy likewise does not require acceptance. However, nothing other than this License grants you permission to propagate or modify any covered work. These actions infringe copyright if you do not accept this License. Therefore, by modifying or propagating a covered work, you indicate your acceptance of this License to do so.

10. Automatic Licensing of Downstream Recipients.
Each time you convey a covered work, the recipient automatically receives a license from the original licensors, to run, modify and propagate that work, subject to this License. You are not responsible for enforcing compliance by third parties with this License.

An "entity transaction" is a transaction transferring control of an organization, or substantially all assets of one, or subdividing an organization, or merging organizations. If propagation of a covered work results from an entity transaction, each party to that transaction who receives a copy of the work also receives whatever licenses to the work the party's predecessor in interest had or could give under the previous paragraph, plus a right to possession of the Corresponding Source of the work from the predecessor in interest, if the predecessor has it or can get it with reasonable efforts.

You may not impose any further restrictions on the exercise of the rights granted or affirmed under this License. For example, you may not impose a license fee, royalty, or other charge for exercise of rights granted under this License, and you may not initiate litigation (including a cross-claim or counterclaim in a lawsuit) alleging that any patent claim is infringed by making, using, selling, offering for sale, or importing the Program or any portion of it.

11. Patents.
A "contributor" is a copyright holder who authorizes use under this License of the Program or a work on which the Program is based. The work thus licensed is called the contributor's "contributor version".

A contributor's "essential patent claims" are all patent claims owned or controlled by the contributor, whether already acquired or hereafter acquired, that would be infringed by some manner, permitted by this License, of making, using, or selling its contributor version, but do not include claims that would be infringed only as a consequence of further modification of the contributor version. For purposes of this definition, "control" includes the right to grant patent sublicenses in a manner consistent with the requirements of this License.

Each contributor grants you a non-exclusive, worldwide, royalty-free patent license under the contributor's essential patent claims, to make, use, sell, offer for sale, import and otherwise run, modify and propagate the contents of its contributor version.

In the following three paragraphs, a "patent license" is any express agreement or commitment, however denominated, not to enforce a patent (such as an express permission to practice a patent or covenant not to sue for patent infringement). To "grant" such a patent license to a party means to make such an agreement or commitment not to enforce a patent against the party.

If you convey a covered work, knowingly relying on a patent license, and the Corresponding Source of the work is not available for anyone to copy, free of charge and under the terms of this License, through a publicly available network server or other readily accessible means, then you must either (1) cause the Corresponding Source to be so available, or (2) arrange to deprive yourself of the benefit of the patent license for this particular work, or (3) arrange, in a manner consistent with the requirements of this License, to extend the patent license to downstream recipients. "Knowingly relying" means you have actual knowledge that, but for the patent license, your conveying the covered work in a country, or your recipient's use of the covered work in a country, would infringe one or more identifiable patents in that country that you have reason to believe are valid.

If, pursuant to or in connection with a single transaction or arrangement, you convey, or propagate by procuring conveyance of, a covered work, and grant a patent license to some of the parties receiving the covered work authorizing them to use, propagate, modify or convey a specific copy of the covered work, then the patent license you grant is automatically extended to all recipients of the covered work and works based on it.

A patent license is "discriminatory" if it does not include within the scope of its coverage, prohibits the exercise of, or is conditioned on the non-exercise of one or more of the rights that are specifically granted under this License. You may not convey a covered work if you are a party to an arrangement with a third party that is in the business of distributing software, under which you make payment to the third party based on the extent of your activity of conveying the work, and under which the third party grants, to any of the parties who would receive the covered work from you, a discriminatory patent license (a) in connection with copies of the covered work conveyed by you (or copies made from those copies), or (b) primarily for and in connection with specific products or compilations that contain the covered work, unless you entered into that arrangement, or that patent license was granted, prior to 28 March 2007.

Nothing in this License shall be construed as excluding or limiting any implied license or other defenses to infringement that may otherwise be available to you under applicable patent law.

12. No Surrender of Others' Freedom.
If conditions are imposed on you (whether by court order, agreement or otherwise) that contradict the conditions of this License, they do not excuse you from the conditions of this License. If you cannot convey a covered work so as to satisfy simultaneously your obligations under this License and any other pertinent obligations, then as a consequence you may not convey it at all. For example, if you agree to terms that obligate you to collect a royalty for further conveying from those to whom you convey the Program, the only way you could satisfy both those terms and this License would be to refrain entirely from conveying the Program.

13. Use with the GNU Affero General Public License.
Notwithstanding any other provision of this License, you have permission to link or combine any covered work with a work licensed under version 3 of the GNU Affero General Public License into a single combined work, and to convey the resulting work. The terms of this License will continue to apply to the part which is the covered work, but the special requirements of the GNU Affero General Public License, section 13, concerning interaction through a network will apply to the combination as such.

14. Revised Versions of this License.
The Free Software Foundation may publish revised and/or new versions of the GNU General Public License from time to time. Such new versions will be similar in spirit to the present version, but may differ in detail to address new problems or concerns.

Each version is given a distinguishing version number. If the Program specifies that a certain numbered version of the GNU General Public License "or any later version" applies to it, you have the option of following the terms and conditions either of that numbered version or of any later version published by the Free Software Foundation. If the Program does not specify a version number of the GNU General Public License, you may choose any version ever published by the Free Software Foundation.

If the Program specifies that a proxy can decide which future versions of the GNU General Public License can be used, that proxy's public statement of acceptance of a version permanently authorizes you to choose that version for the Program.

Later license versions may give you additional or different permissions. However, no additional obligations are imposed on any author or copyright holder as a result of your choosing to follow a later version.

15. Disclaimer of Warranty.
THERE IS NO WARRANTY FOR THE PROGRAM, TO THE EXTENT PERMITTED BY APPLICABLE LAW. EXCEPT WHEN OTHERWISE STATED IN WRITING THE COPYRIGHT HOLDERS AND/OR OTHER PARTIES PROVIDE THE PROGRAM "AS IS" WITHOUT WARRANTY OF ANY KIND, EITHER EXPRESSED OR IMPLIED, INCLUDING, BUT NOT LIMITED TO, THE IMPLIED WARRANTIES OF MERCHANTABILITY AND FITNESS FOR A PARTICULAR PURPOSE. THE ENTIRE RISK AS TO THE QUALITY AND PERFORMANCE OF THE PROGRAM IS WITH YOU. SHOULD THE PROGRAM PROVE DEFECTIVE, YOU ASSUME THE COST OF ALL NECESSARY SERVICING, REPAIR OR CORRECTION.

16. Limitation of Liability.
IN NO EVENT UNLESS REQUIRED BY APPLICABLE LAW OR AGREED TO IN WRITING WILL ANY COPYRIGHT HOLDER, OR ANY OTHER PARTY WHO MODIFIES AND/OR CONVEYS THE PROGRAM AS PERMITTED ABOVE, BE LIABLE TO YOU FOR DAMAGES, INCLUDING ANY GENERAL, SPECIAL, INCIDENTAL OR CONSEQUENTIAL DAMAGES ARISING OUT OF THE USE OR INABILITY TO USE THE PROGRAM (INCLUDING BUT NOT LIMITED TO LOSS OF DATA OR DATA BEING RENDERED INACCURATE OR LOSSES SUSTAINED BY YOU OR THIRD PARTIES OR A FAILURE OF THE PROGRAM TO OPERATE WITH ANY OTHER PROGRAMS), EVEN IF SUCH HOLDER OR OTHER PARTY HAS BEEN ADVISED OF THE POSSIBILITY OF SUCH DAMAGES.

17. Interpretation of Sections 15 and 16.
If the disclaimer of warranty and limitation of liability provided above cannot be given local legal effect according to their terms, reviewing courts shall apply local law that most closely approximates an absolute waiver of all civil liability in connection with the Program, unless a warranty or assumption of liability accompanies a copy of the Program in return for a fee.

END OF TERMS AND CONDITIONS

How to Apply These Terms to Your New Programs
If you develop a new program, and you want it to be of the greatest possible use to the public, the best way to achieve this is to make it free software which everyone can redistribute and change under these terms.

To do so, attach the following notices to the program. It is safest to attach them to the start of each source file to most effectively state the exclusion of warranty; and each file should have at least the "copyright" line and a pointer to where the full notice is found.

    <one line to give the program's name and a brief idea of what it does.>
    Copyright (C) <year>  <name of author>

    This program is free software: you can redistribute it and/or modify
    it under the terms of the GNU General Public License as published by
    the Free Software Foundation, either version 3 of the License, or
    (at your option) any later version.

    This program is distributed in the hope that it will be useful,
    but WITHOUT ANY WARRANTY; without even the implied warranty of
    MERCHANTABILITY or FITNESS FOR A PARTICULAR PURPOSE.  See the
    GNU General Public License for more details.

    You should have received a copy of the GNU General Public License
    along with this program.  If not, see <https://www.gnu.org/licenses/>.
Also add information on how to contact you by electronic and paper mail.

If the program does terminal interaction, make it output a short notice like this when it starts in an interactive mode:

    <program>  Copyright (C) <year>  <name of author>
    This program comes with ABSOLUTELY NO WARRANTY; for details type `show w'.
    This is free software, and you are welcome to redistribute it
    under certain conditions; type `show c' for details.
The hypothetical commands `show w' and `show c' should show the appropriate parts of the General Public License. Of course, your program's commands might be different; for a GUI interface, you would use an "about box".

You should also get your employer (if you work as a programmer) or school, if any, to sign a "copyright disclaimer" for the program, if necessary. For more information on this, and how to apply and follow the GNU GPL, see https://www.gnu.org/licenses/.

The GNU General Public License does not permit incorporating your program into proprietary programs. If your program is a subroutine library, you may consider it more useful to permit linking proprietary applications with the library. If this is what you want to do, use the GNU Lesser General Public License instead of this License. But first, please read https://www.gnu.org/licenses/why-not-lgpl.html.
'''

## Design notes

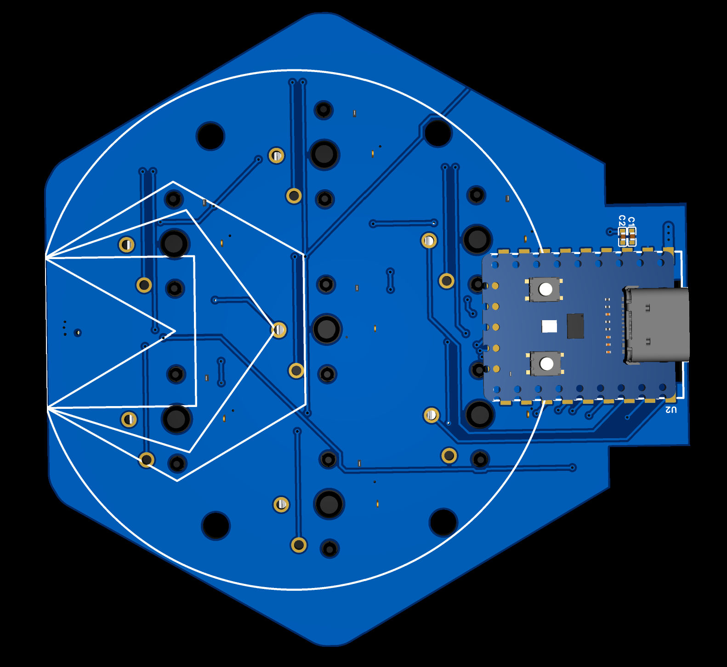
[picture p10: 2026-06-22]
assets/images/pcb_3d_bottom_view.png

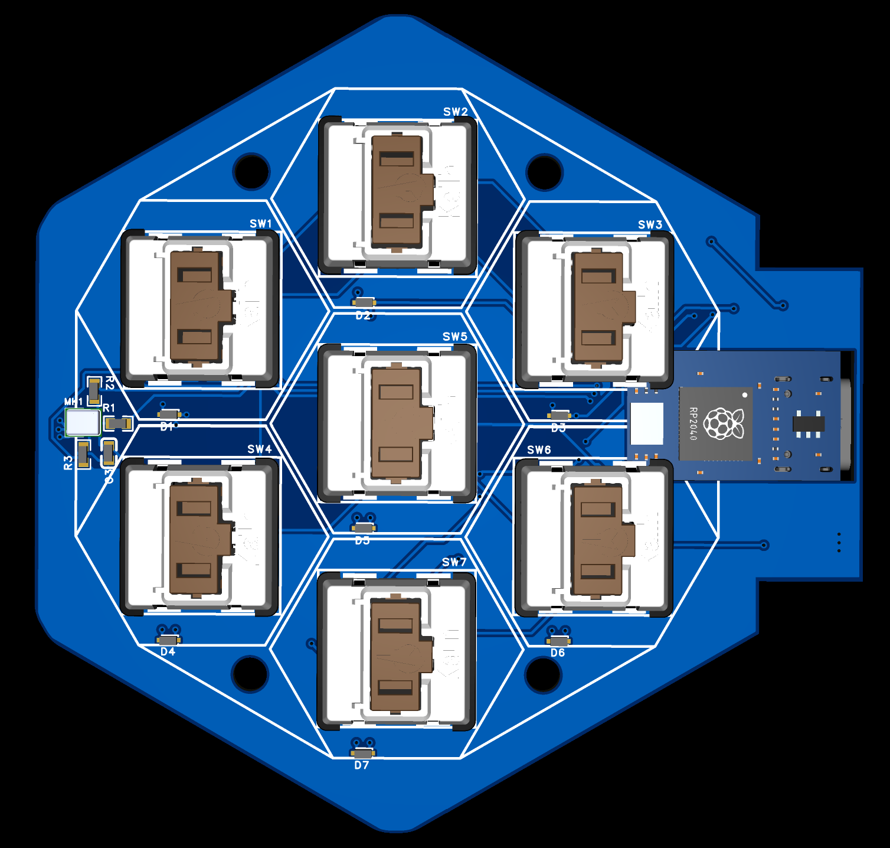
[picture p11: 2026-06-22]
assets/images/pcb_3d_top_view.png

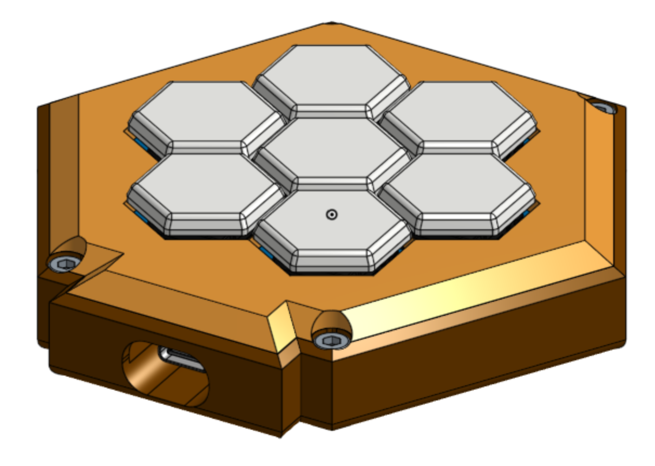
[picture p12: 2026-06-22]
assets/images/cad_top_left_corner_view.png

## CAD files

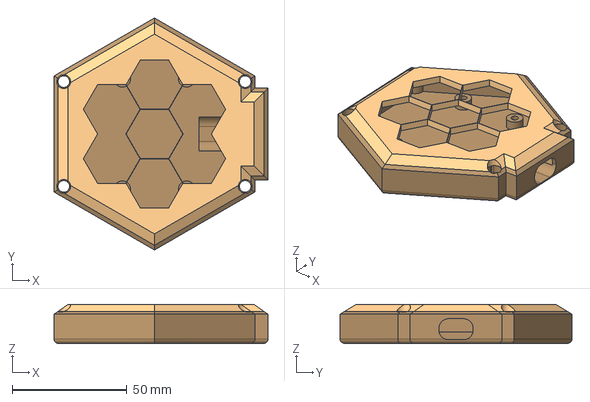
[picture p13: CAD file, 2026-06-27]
hardware/macragon_case_part_studio.step
93.1 x 100.9 x 17.0 mm

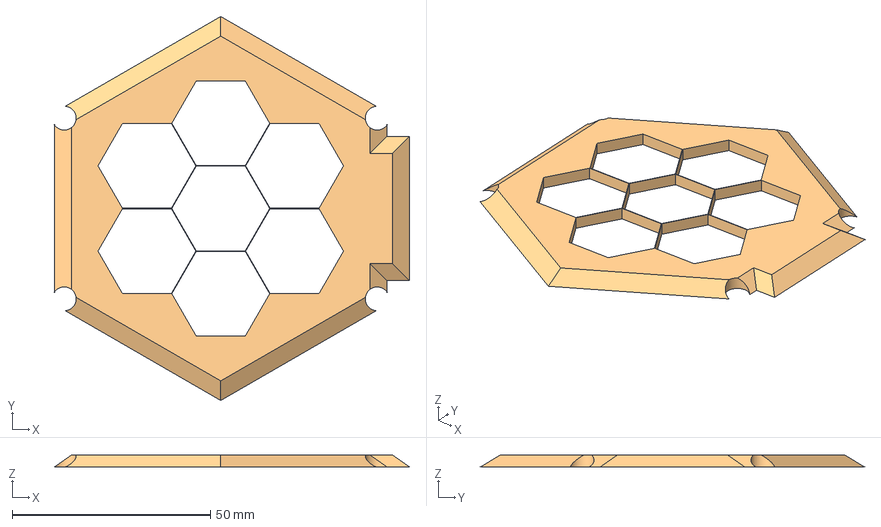
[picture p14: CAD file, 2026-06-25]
hardware/case_top.step
89.5 x 96.8 x 3.00 mm

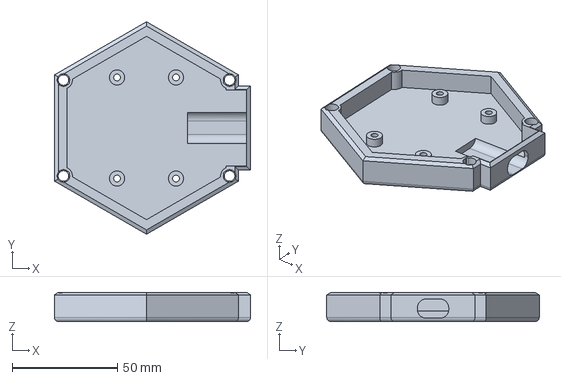
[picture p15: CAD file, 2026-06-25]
hardware/case_body.step
93.1 x 100.9 x 14.0 mm

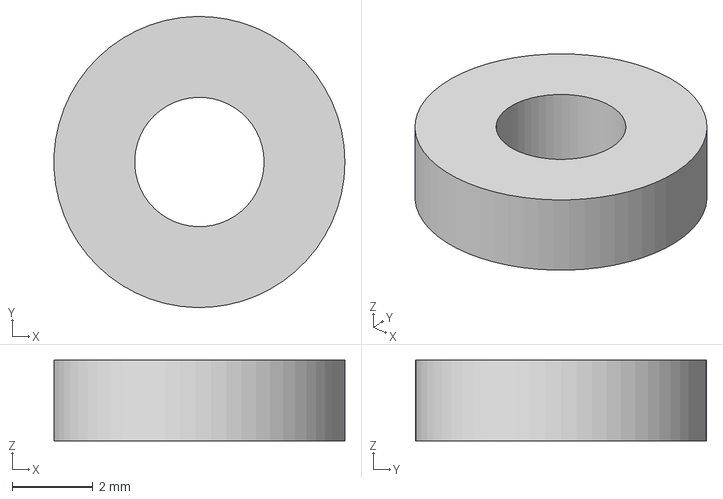
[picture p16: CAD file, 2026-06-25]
hardware/pcb_to_screw_spacer.step
7.19 x 7.20 x 2.00 mm

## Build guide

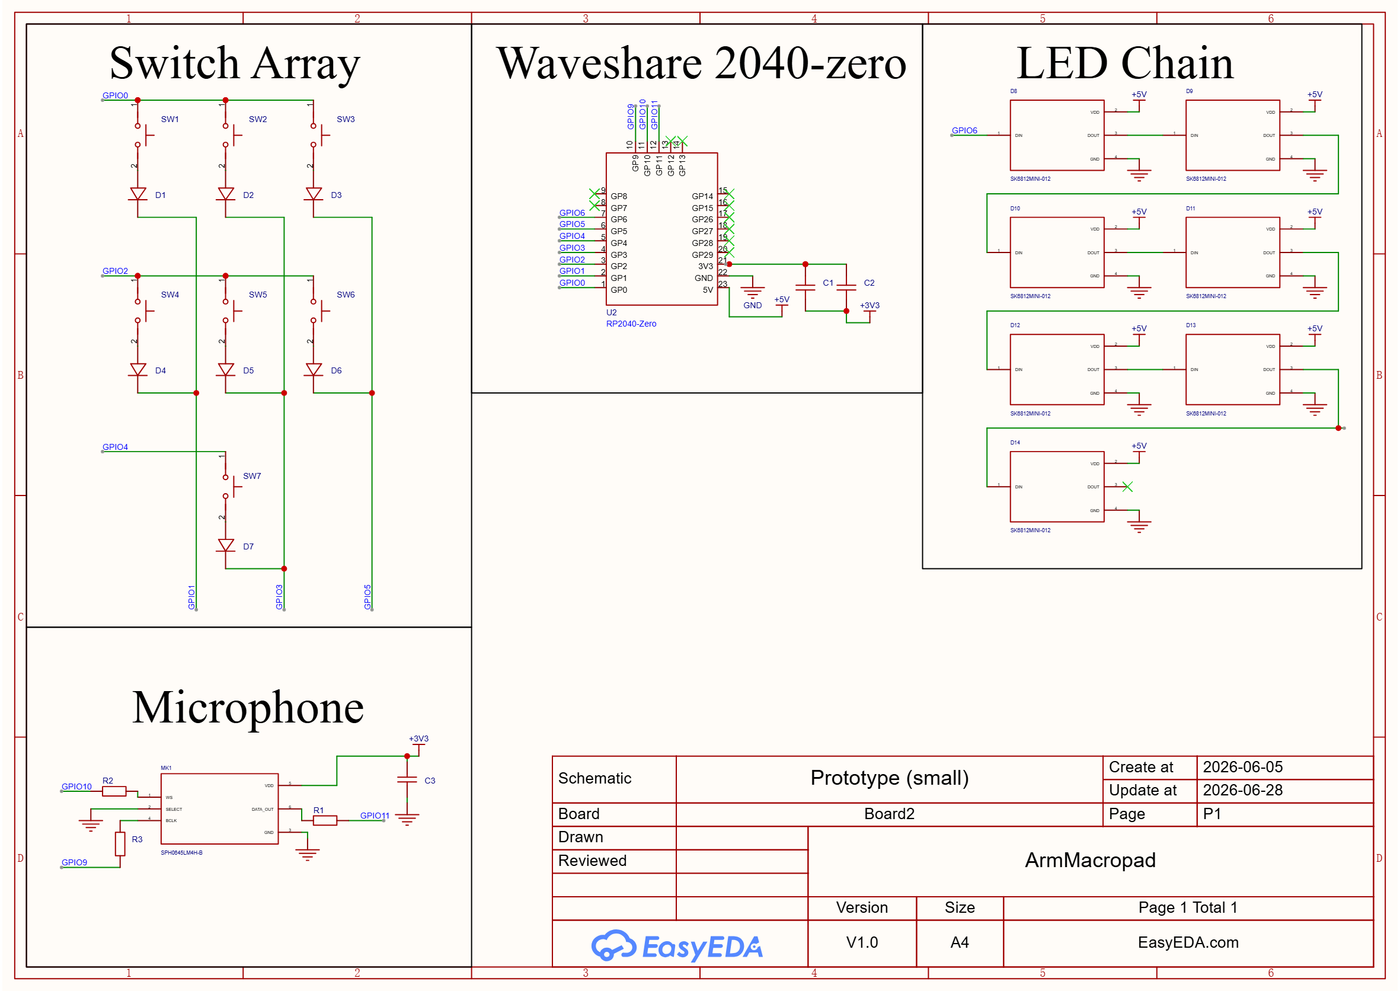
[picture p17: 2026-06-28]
hardware/macragon_wiring_schematic.png

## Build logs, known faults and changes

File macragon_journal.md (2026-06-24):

# Hexagon Macropad — Journal Export

- Exported at: 2026-06-24T16:50:42Z
- Project ID: 3803
- Entries: 34

## Entry 1
- ID: 8937
- Author: apricity
- Created At: 2026-05-24T18:25:57Z

### Content

Since I can't work on the hardware for the 4-DOF robotic arm project I have been working on over the summer, I have decided to instead work on the user-interfacing hardware. For this purpose, per the original constraints of the robotic arm project, I plan on making a unique macropad with large buttons.
download (11).jfif

### Recording Links

- https://lookout.hackclub.com/api/media/ee536b7e-b06b-42a2-839f-15fc92be629d/video.mp4

## Entry 2
- ID: 9021
- Author: apricity
- Created At: 2026-05-25T03:15:54Z

### Content

Continuing learning about pcb design, planning on making one for macro pad. Need to decide what buttons to put on macro pad and case design.

il_fullxfull.6283624459_p4b3.avif 

### Recording Links

- https://lookout.hackclub.com/api/media/885ad1dc-a7d9-4331-8946-17251813929e/video.mp4

## Entry 3
- ID: 9500
- Author: apricity
- Created At: 2026-05-27T01:18:05Z

### Content

Watched a tutorial to learn more about how macropads are made (so much Python *crying emoji*). Will start prototype macropad this week, Saturday? Soup guilt-tripping me to keep up my streak. Hopefully learning through tutorials counts toward the 60 hrs?



### Recording Links

- https://lookout.hackclub.com/api/media/39c5c431-b44b-497f-ade3-53c8b83d3bd8/video.mp4

## Entry 4
- ID: 10804
- Author: apricity
- Created At: 2026-06-01T02:59:55Z

### Content

Working on USB hub guided project to learn more about PCB design and to increase familiarity with said process in preparation for making own macropad PCB. Finished schematic (intend to go back later to change usb-a ports to usb 3.0 compatible (or maybe even 3.2))





### Recording Links

- https://lookout.hackclub.com/api/media/6cf68df5-e3f6-460f-818b-c6c30201a68b/video.mp4

## Entry 5
- ID: 11042
- Author: apricity
- Created At: 2026-06-02T02:55:51Z

### Content

Continuing work on usb  hub guided project. Did math for alignment because why hexagon??????? Just realized input port + computer or whatever will probably block some functionality to forward ports, or just inconv - 10:54 PM 6/1/2026

inspiration:


### Recording Links

- https://lookout.hackclub.com/api/media/a0b064db-3f59-4ffa-9818-216813703baa/video.mp4
- https://lookout.hackclub.com/api/media/e65ab3b7-af87-4485-89e9-a01246eaa2df/video.mp4
- https://lookout.hackclub.com/api/media/9d8c8bc6-d60b-45ff-8d2f-cab62aec3f97/video.mp4

## Entry 6
- ID: 11273
- Author: apricity
- Created At: 2026-06-03T02:13:01Z

### Content

Continued routing, spent way too long trying to get the usb ports aligned in the middle of the hexagon side (aligning on 60 degrees is a pain). Also learned how to use vias!



### Recording Links

- https://lookout.hackclub.com/api/media/f728c1cb-b7a3-4690-8cc1-51aac2e09f44/video.mp4

## Entry 7
- ID: 11497
- Author: apricity
- Created At: 2026-06-04T00:34:45Z

### Content

Finished up major components of guided project. Hexagonal USB Hub components in place, just need to clean up corners and DRC errors (adjust the settings on differential pairs and some components too close to one another.


### Recording Links

- https://lookout.hackclub.com/api/media/f55f7da6-1bff-4dea-ae23-99d580611e34/video.mp4

## Entry 8
- ID: 11520
- Author: apricity
- Created At: 2026-06-04T03:21:14Z

### Content

Finished off guided project (well, with the touch of hexagons are the bestagons). Now prepping to start my own design for the arm macropad, albeit I'll have to reconsider using hexagonal keys (at the most, square keys with hexagonal tops).



### Recording Links

- https://lookout.hackclub.com/api/media/b43b3e33-59eb-4a80-8f86-81ad1c401003/video.mp4

## Entry 9
- ID: 11586
- Author: apricity
- Created At: 2026-06-04T10:23:33Z

### Content

Started planning key layout for prototype macropad. Looked at other potential key layouts (0xc not really "hexagonal" in shape, prob will stick with normal hexagon). Looked at below image for inspiration on how to make macropad relatively flat (modular keys would be cool, but will have to see) and compact (absolutely rgb, need to find suitable key cover method)



### Recording Links

- https://lookout.hackclub.com/api/media/a8366e80-46e3-47e1-8391-7e909a55a117/video.mp4

## Entry 10
- ID: 11797
- Author: apricity
- Created At: 2026-06-05T08:07:05Z

### Content

Trying to decide on switches since no one likes too tall macropad. None of the ones looked at have easyeda schematics :cryingemoji:

short switch bois


### Recording Links

- https://lookout.hackclub.com/api/media/cc5c249a-8e29-4eae-9d15-9f1a18bb3cf5/video.mp4

## Entry 11
- ID: 11840
- Author: apricity
- Created At: 2026-06-05T14:21:18Z

### Content

Deciding whether or not to use KiCad for macropad project since actually has footprints for cherry mx ultra-low-profile switches. However, decided that the learning curve is not worth it right now. In addition, have to figure out how to implement a keyboard matrix if all keys are hexagonally arranged So sleep deprived, going with Cherry MX 1s for now. Still need to figure out how to reasonably wire up the rest of the RPI Pico 2W pins. Also, need to think through firmware (looking at some version/variant of QMK? + decide how advanced one would like to go with the firmware)


### Recording Links

- https://lookout.hackclub.com/api/media/d9e93042-ca00-434b-b006-f25f1897a70c/video.mp4
- https://lookout.hackclub.com/api/media/d47c01c9-d684-43ff-b4f9-dd7e69e98db7/video.mp4

## Entry 12
- ID: 12064
- Author: apricity
- Created At: 2026-06-06T15:51:57Z

### Content

WiFi quite slow, so work progressed fairly little. Computer ran out of battery (no compatible power outlets) :( so missed like 2-3 hours of potential working time. Will pick up tomorrow, definitely going with EasyEDA for schematic design. Need to look more into QMK, wiring schematic square but macropad hexagonal. (internet traffic peaking around 360kb/s :cryingemoji:)



### Recording Links

- https://lookout.hackclub.com/api/media/853ed06a-1763-4332-8319-a301c2d95fcd/video.mp4
- https://lookout.hackclub.com/api/media/736e4785-8b08-4518-8659-515d2e7c763a/video.mp4
- https://lookout.hackclub.com/api/media/4547714d-8a63-4d7a-abc6-6923e5d42c30/video.mp4

## Entry 13
- ID: 12251
- Author: apricity
- Created At: 2026-06-07T10:19:33Z

### Content

Setup keyboard matrix (properly this time), and selected a different microcontroller. Switched from Raspberry Pico to 2040-zero for usb-c port and smaller form factor. 6/7/2026, 6:18 PM CST



### Recording Links

- https://lookout.hackclub.com/api/media/7487f7df-d53f-4f68-b46c-49c1e75e3066/video.mp4

## Entry 14
- ID: 12531
- Author: apricity
- Created At: 2026-06-08T16:00:58Z

### Content

Working on pcb design switched switches again over to silenter ones for ease of use during class and to not be too loud. Found decent hex keycaps

https://git.s-ol.nu/hw/kicad-lib/-/raw/main/spec.pdf


### Recording Links

- https://lookout.hackclub.com/api/media/8af40bf8-59c5-4077-a975-87f8a8bd40a9/video.mp4
- https://lookout.hackclub.com/api/media/886c1887-9425-4649-864b-da199acfaf62/video.mp4
- https://lookout.hackclub.com/api/media/d23a0093-5360-480d-ad66-070796a02a7f/video.mp4

## Entry 15
- ID: 12755
- Author: apricity
- Created At: 2026-06-09T13:06:02Z

### Content

Continued working on pcb, arranged switches and diodes in correct coordinate position (down to 3 digits because perfectionism) with relative offsets. Switched to actually existing LCSC diode parts, struggling with an issue where easyeda can't label parts properly because of multiple net labels on connected wires (pending help response from #electronics). Realized that I forgot to pause one of the recordings yesterday at the end and recorded me accidentally switching workspaces to an open Duolingo tab on the other, lol. Sorry! 6/9/2026, submitted at 9:05 PM/21:05, CST.

Behold, the source of today's main frustration:


### Recording Links

- https://lookout.hackclub.com/api/media/e5032b5d-cce3-41e6-addc-975bacaa624c/video.mp4
- https://lookout.hackclub.com/api/media/855c0e84-3678-4f04-8d31-643857c4865f/video.mp4

## Entry 16
- ID: 12771
- Author: apricity
- Created At: 2026-06-09T14:58:20Z

### Content

Finished placement of keys and diodes, resolved issue with multiple net lables (overlapping t-junctions *facepalm*). Finished rewiring traces after issue with microprocessor placement (didn't realize prongs from choc switches would protrude on other side, facepalm again). So, moved processor, with better usb-c port access and rewired. Also, I just realized there's now a giant hole in my board (maybe for room for stuff on bottom of 2040-zero?).





switch 3d models being weird

### Recording Links

- https://lookout.hackclub.com/api/media/b057774f-2436-4f92-a125-564ade29b8de/video.mp4

## Entry 17
- ID: 12922
- Author: apricity
- Created At: 2026-06-10T03:49:05Z

### Content

Lapse down :cryingemoji:, but fixed now! Added keycap outlines for better understanding layout and mostly remade the board outline. Needed to be adjusted to be smaller (I might have to look into better support for the microcontroller later). (Couldn't figure out smart dimension tool)

Realized that I was being an idiot and that the RP2040-zero wouldn't fit on the smaller board outline. No save file with larger outline and latest changes :cryingemoji:, so had to remake. Used dimensions to align points, almost certainly a faster and cleverer way exists. Then, readjusted the silkscreen layouts for the keycaps to be more accurate and stop being at wonky angles to each other (for my peace of mind). Found and donwloaded better 3d models for RP2040-zero (took _WAYYYYY_ too long).

THIS SHOULD NOT HAVE TAKEN THIS LONGGGG :sort of crying emoji: :tired emoji:
  
Screenshot 2026-06-10 114709.png
Screenshot 2026-06-10 114648.png
Screenshot 2026-06-10 114508.png

### Recording Links

- https://www.youtube.com/watch?v=lQQvc7-vEgY
- https://lookout.hackclub.com/api/media/22602189-662c-475f-895f-4737dd60ca59/video.mp4

## Entry 18
- ID: 12996
- Author: apricity
- Created At: 2026-06-10T11:45:27Z

### Content

Finishing up some final touches, uploading 3d models for incomplete parts in preparation for export to Onshape for case design (hopefully with keycaps!). Not fully sure why, but the simple silkscreen design I wanted to do took over an hour :cryingemoji: :frustration emoji: I'm sure I'll find a pre-made version later. Between the sleep deprivation and the hours spent staring at a screen, I'm not even quite fully sure about everything I did at the beginning of this session.



### Recording Links

- https://lookout.hackclub.com/api/media/2528de81-4d9d-4457-8136-97c1c35a1f4e/video.mp4

## Entry 19
- ID: 13244
- Author: apricity
- Created At: 2026-06-11T15:33:50Z

### Content

Got necessary files into Onshape to start designing the case tomorrow. Had to redo wiring for all the switches, adjust board outline, and move the microprocessor because forgot to account for keycaps :hmm:. The required orientation of keycaps for the design to work required all the switches to be turned 180, since choc v1 mounting pattern. Welp, case design starts tomorrow! Thank goodness someone else has already made keycaps:

Screenshot 2026-06-11 232908.png

### Recording Links

- https://lookout.hackclub.com/api/media/de4b033f-1de8-49b1-a0e2-bbfac8bddc54/video.mp4
- https://lookout.hackclub.com/api/media/a5916d46-4e31-4ef3-8105-28321aeb29ea/video.mp4

## Entry 20
- ID: 13461
- Author: apricity
- Created At: 2026-06-12T14:26:31Z

### Content

Continued work on macropad case, had to revise PCB board outline to better fit ergonomics. Thinking of making a tiling system (like gridfinity but hexagons) so this macropad works with the previous usb hub that I forgot to log on a different project. Case still a prototype, needed to revise size. Can't figure out a simple way to get all the dozens of pcb import part studios into one file (did it only once, somewhat intentionally) :cryingemoji:



### Recording Links

- https://lookout.hackclub.com/api/media/7f8f9409-3c6c-44df-a169-e79532c7efc8/video.mp4
- https://lookout.hackclub.com/api/media/00198b97-ad06-4231-b3c9-b32963241824/video.mp4

## Entry 21
- ID: 13475
- Author: apricity
- Created At: 2026-06-12T15:35:48Z

### Content

Finished up preliminary case (albeit, have no idea on the ergonomics, prob will either make cutout or increase chamfer on ed). Next up is detailing and weight trimming. Still need so many more hours :crying emoji: :morecryingemojibecauseoneisn'tenough:

Tostart: zine, integration with usb hub, grid lattice


 ge

### Recording Links

- https://lookout.hackclub.com/api/media/225946e5-7568-4223-b4e2-f96842896dcc/video.mp4

## Entry 22
- ID: 13742
- Author: apricity
- Created At: 2026-06-13T15:18:52Z

### Content

Added RGB LEDs since Choc switches don't come with them, took a while to find one that fit. Originally was going to use MINI-E variant but that would have required moving the RP2040 and rewiring all those traces again, so stuck with top-mounted LEDs. Had to redo some traces, a couple of lines needed multiple vias to get to the RP2040, added a 5v plane. Expected amperage should be under 0.5 Amps (60 milliamps per LED at full draw and Choc switches, excluding RP2040-zero) going the 5v plane. 
 
Screenshot 2026-06-13 231421.png
<!-- Uploading Screenshot 2026-06-13 231401.png (624 KB)... 72% -->

### Recording Links

- https://lookout.hackclub.com/api/media/661fca5c-33fd-4650-aa9b-281e85cd5c29/video.mp4
- https://lookout.hackclub.com/api/media/2a7bdb91-f4e7-414b-a8e6-6b44c1d39fbd/video.mp4

## Entry 23
- ID: 13990
- Author: apricity
- Created At: 2026-06-14T15:11:48Z

### Content

Decided to add microphone cause why not, let's make my life harder as I get closer to the deadline. Also had to revise diodes because I didn't realize that the footprint hadn't changed over (right manufacturer, wrong part number, wrong footprint, right 3d model but I changed it) and somehow I didn't realize the footprints in use were the through hole ones. Took quite a long time to rewire everything to fit and to add the new wires for capacitors, resistors, etc. linked to the mic. Not exactly looking forward to debugging the code for the mic on top of KMK.

(New mic cluster in left! Albeit mic is facing out the bottom)
Screenshot 2026-06-14 231054.png

### Recording Links

- https://lookout.hackclub.com/api/media/e350127b-ab83-445d-9607-70010d1bb5fb/video.mp4

## Entry 24
- ID: 13998
- Author: apricity
- Created At: 2026-06-14T15:22:05Z

### Content

GAHHHHHHHHH (sorry, lost around an hour of potentially loggable work time due to lookout page not loading and lookout just repeatedly disconnecting) :cryingemojiiiiiii::::. Setting up some preliminary macros for kmk for the macropad. I currently have an idea for multiple "initialization" buttons (for example, double tap button 1 to launch all the tabs + apps you want for a certain workflow, maybe triple tap to close), sort of like setting up apps in Windows to auto launch, but you have better control. Also, this way is easier, you have more configurations of apps to launch (work, gaming, etc.), and you can port it between computers w/ the macropad. Prob already exists, but does it exist as a _hexagon_? Planning on using Win+S to launch different apps. Perhaps I can finally automate the ever-growing setups and signins to run while my teacher is talking, etc. (they can't tell me off for using my computer if it's launching on it's own!)

Fallout "init" button for all my fallout-related apps


### Recording Links

- https://lookout.hackclub.com/api/media/b13648ab-edc1-4505-ab68-bf071821ba3d/video.mp4
- https://lookout.hackclub.com/api/media/9d74e6c4-e5cd-4c56-86da-72e0ca82f7cf/video.mp4

## Entry 25
- ID: 14266
- Author: apricity
- Created At: 2026-06-15T16:01:35Z

### Content

Continued adding macros and custom keys for macropad. Preliminary keys finalized, with microphone code starting tomorrow. Current plan is to have two preset initialization configurations, with layer implementation if time (unlikely). Final project will hopefully include layers synced to RGB LEDs to indicate which layer. (i.e., CAD layer, Code layer, etc.) Albeit, I suspect getting Windows to recognize the macropad as a USB Audio device will be slightly tricky, but hopefully can figure it out. Current plan is to work on Zine and Github repo while on train on Wednesday, maybe submit by Thursday.

__Screenshot 2026-06-15 235316.png

### Recording Links

- https://lookout.hackclub.com/api/media/a624a531-d730-4c37-b355-f5bd233a0987/video.mp4

## Entry 26
- ID: 14490
- Author: apricity
- Created At: 2026-06-16T09:41:46Z

### Content

I think I have finished writing v1 of the firmware. Of course, I can't test anything because there's no use in ordering a microcontroller if by the time it gets anywhere I'll be gone. Repo, zine, and libraries still need to be made. Also, can't lib setup might be a bit weird since all the stuff is meant to be installed to a circuitpython compatible board. For some reason, during the morning (and yesterday night), Lookout kept stalling out or refusing to record past a point



### Recording Links

- https://lookout.hackclub.com/api/media/5ca1f609-9a2f-4330-bac9-eca0bf964531/video.mp4
- https://lookout.hackclub.com/api/media/04733b78-412e-418e-b696-0953318a7274/video.mp4

## Entry 27
- ID: 14553
- Author: apricity
- Created At: 2026-06-16T15:38:48Z

### Content

In the morning, continued working on KMK stuff. Decided to  leave voice keyboard until version 2 :(, because circuitpython doesn't seem to have much interaction stuff as a USB Audio device. Perhaps v2 can use C/C++ and implement voice keyboard better. Did add keyboard layers tho.

Trying to look at inspiration and guidelines on what makes a good zine/repo. (Also, whoever made doom run in a pdf, kudos to you, that is awesome)

Tried to do some design on Figma, but WiFi currently too slow to support (ran out of high speed data for today since traveling)

Looked at NotARoomba's repo for a sense of how to better organize one


Screenshot 2026-06-16 233801.png

### Recording Links

- https://lookout.hackclub.com/api/media/8d81c583-1f86-4bdc-9074-4b3b4d491da8/video.mp4
- https://lookout.hackclub.com/api/media/2e7872eb-3ef8-49fa-8910-9c9b5594b18d/video.mp4

## Entry 28
- ID: 14766
- Author: apricity
- Created At: 2026-06-17T14:36:36Z

### Content

Since I've decided to leave off on the microphone firmware until v2, I started (well, tried starting) work on my zine. My plans were thwarted by an absence of high-speed wifi, and as such progress was extremely frustrating. I don't fully understand how I can get better reception at 200 kph than in a stationary apartment. Just need to finish up a case CAD, and make repo and zine. I've decided to go with Canva for zine design since I don't have enough time to learn Figma before the zine is due.

Apparently I have a lot of tiny recordings of me just trying to get stuff to load? Sorry review team! Lookout was behaving a bit weirdly yesterday and the day before (kept stopping my recording) so perhaps it stems partially from that.

I read somewhere that my journals might include crashouts, and if you have ever stared at a Gmail loading screen for a literal half hour (still didn't end up loading) because you needed an important email, and didn't crash out at least a little, your patience has my utmost respect. Or today, with nothing loading for a solid half an hour. I managed in half an hour to ... look at a github repo. Kind of. GAHHH

Ended up managing to import zine template into Canva and make a github repo, Onshape still didn't load. Hopefully it loads tomorrow?

Onshape, use polar-bear-in-snowstorm! (It was very effective):



### Recording Links

- https://lookout.hackclub.com/api/media/95eeb0a4-d155-4f89-81ab-6a45ec0046e1/video.mp4
- https://lookout.hackclub.com/api/media/5787f40c-2269-49a6-818e-085d4be1bc1b/video.mp4
- https://lookout.hackclub.com/api/media/069e1690-d7dc-437d-92cc-fdb5a1aecb41/video.mp4
- https://lookout.hackclub.com/api/media/4a9c4b58-9251-409a-9e44-030812b6de77/video.mp4
- https://lookout.hackclub.com/api/media/cfd7953b-eaae-4834-93b3-cbb42b049183/video.mp4
- https://lookout.hackclub.com/api/media/3a0d1724-7638-4994-aec9-699d1b6a22db/video.mp4
- https://lookout.hackclub.com/api/media/8533bd5d-654c-4d6c-8008-79f4fa6d7975/video.mp4
- https://lookout.hackclub.com/api/media/4213e9f3-7aeb-420e-962c-d1653325dfc7/video.mp4

## Entry 29
- ID: 15003
- Author: apricity
- Created At: 2026-06-18T15:38:37Z

### Content

Finished the CAD assembly! Probably spent a bit too long on aesthetics but oh well. _Really_ need to get my Github repo set up and finish the zine. Hopefully can get at least a couple hours in tomorrow otherwise I might be a little in trouble. The untitled recording is more CAD work I think. using M3 hardware for mounting, case planned to be made out of ABS (worried about the slats between keys though, might just eliminate those). Canva is going well, I have an idea for overlaid semi-transparent images of my project w/ hexagons everywhere. Hexagons, after all, are the bestagons.

Screenshot 2026-06-18 173745.png

Screenshot 2026-06-18 170635.png
Screenshot 2026-06-18 170417.png
Screenshot 2026-06-18 151000.png

### Recording Links

- https://lookout.hackclub.com/api/media/a789aac5-da3f-4ede-b669-f16eef097d57/video.mp4
- https://lookout.hackclub.com/api/media/6ddb0795-1c2c-4361-87b7-472b09fb8271/video.mp4
- https://lookout.hackclub.com/api/media/bd9dd4af-0381-43db-879f-11a2d89e55f8/video.mp4

## Entry 30
- ID: 15270
- Author: apricity
- Created At: 2026-06-19T15:56:59Z

### Content

Finished up mounting hardware for CAD. Also did some more work on zine, attempting to implement image layering idea. However, manually trimming screenshot backgrounds took a good deal of time. Towards the end, I was thwarted by Canva not letting me move elements, but I had surprisingly good connection for being in a tunnel in a mountain. I spent around close to four hours recording, but it seems that Lookout did not track a significant chunk of that. 17 minutes was lost due to me forgetting to unpause after a connection drop, but not fully sure about the rest. Perhaps it is added up from the time lost while Lookout is uploading images.

Current zine (still unable to move elements)


### Recording Links

- https://lookout.hackclub.com/api/media/b91c22bf-50c5-4a4a-9747-dfde06601a66/video.mp4

## Entry 31
- ID: 15630
- Author: apricity
- Created At: 2026-06-20T15:58:13Z

### Content

### Saturday, 6/20/2026:

Almost there, just need to finish my zine and Github repo. NotARoomba's Github repo seems to be very well organized, and due to my lack of experience I have been looking at theirs.

The Github guide on basic use of markdown (https://docs.github.com/en/get-started/writing-on-github/getting-started-with-writing-and-formatting-on-github/basic-writing-and-formatting-syntax) has also been quite useful since I've never used markdown before when writing a REadMe.

The images I've used were imported from Onshape into Canva and then I manually removed the background, since the Canva tool for that requires payment. I think I need to make the PCB more visible instead of the current semi-transparent layout for clearer functionality so that will be next on my list of edits.



I've had to manually edit the BOM exported since the normal one wasn't really useful with it's orderings and columns.

### Recording Links

- https://lookout.hackclub.com/api/media/a5d51757-04b8-4a5d-848b-eb87afb70749/video.mp4

## Entry 32
- ID: 15673
- Author: apricity
- Created At: 2026-06-20T17:21:45Z

### Content

### Sunday, 6/21/2026 (1:15 AM, CST)

I've finished the zine, and made it clear by adding a description and improving spacing between text. In addition, I fixed an issue where some text was in the red zone for potentially being cutoff (I forgot to unhide the borders that marked the zones). Added a QR code to the repo (hexagonal of course). In addition, there is now another image of the PCB to help make it clearer instead of the only image being semi-transparent.

Github repo now has the zine on it along with a BOM that includes PCB + Stencil + Cheapest Shipping price. It is quite imperfect, and I will keep improving it in the days to come. I faced issues because I am not familiar with markdown, but through reading Github docs and Google, that has been temporarily overcome.



### Recording Links

- https://lookout.hackclub.com/api/media/909ce73a-90d3-4841-87e4-f0398b7df1f6/video.mp4

## Entry 33
- ID: 16090
- Author: apricity
- Created At: 2026-06-23T15:57:37Z

### Content

# 6/23/2026 Log

Updated README.md with actual prices (purchasing from LCSC and amazon.com w/ personal Prime account). Currently the main tasks left are just cleanup work with stuff that I missed earlier. 

CAD, PCB, and firmware for v1 are all complete and uploaded to the repository. I decided to simply stick a 'total' entry into the BOM instead of making a separate page, hopefully it makes readibility and finding items easier. I also added an entry for price for each item and the lowest necessary quantity that they could be purchased in.



### Recording Links

- https://lookout.hackclub.com/api/media/095d7da4-5f6e-4c6d-a834-3a659e79a487/video.mp4
- https://lookout.hackclub.com/api/media/78b04cad-a2b9-4fa8-ad93-fabefd1af17d/video.mp4

## Entry 34
- ID: 16155
- Author: apricity
- Created At: 2026-06-24T15:59:43Z

### Content

# 6/24/2026

Since the BOM imported from EasyEDA did not have commas, it caused a bit of a struggle fixing them. (I suppose I should have seen the lack of commas in a comma separated value file coming.) So, after much manual comma adding, and accidentally deleting some lines, the commas in the bom are fixed and correctly formatted



### Recording Links

- https://lookout.hackclub.com/api/media/a2e1617d-fc00-4ceb-bce7-e45157016723/video.mp4
- https://lookout.hackclub.com/api/media/c309c7fe-9b2a-4645-a979-cfeaafbf7f3e/video.mp4

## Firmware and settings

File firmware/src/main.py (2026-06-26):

""" KMK firmware written for a hexagonal macropad controlled by a Waveshare RP2040-zero. 
Includes control of a RGB LED strip of SK6812MINI-Bs, 
multiple keyboard layers that the LEDs are synced to, and
the ability to toggle between them."""

import board  

from kmk.kmk_keyboard import KMKKeyboard
from kmk.keys import KC, Key
from kmk.scanners import DiodeOrientation
from kmk.scanners import MatrixScanner
from kmk.modules.macros import Macros, Press, Release, Delay, Tap
from kmk.modules.tapdance import TapDance
from kmk.modules.layers import Layers
from kmk.extensions.rgb import RGB 
  
NUM_LEDS = 7, 

RGB_CHAIN_HEAD_PIN = board.GP6
BIT_CLOCK_PIN = board.GP9
WORD_SELECT_PIN = board.GP10
DATA_IN_PIN = board.GP11
 
layers_module = Layers()

keyboard = KMKKeyboard()
keyboard.modules.append(Macros())
keyboard.modules.append(TapDance())
keyboard.modules.append(Layers())

col_pins = (board.GP1, board.GP3, board.GP5)
row_pins = (board.GP0, board.GP2, board.GP4)

diode_orientation = DiodeOrientation.ROW2COL 

class LayerColor(RGB):
    def set_light_layer(self, layer):
        if layer == 0:
            self.set_animation(3)
        elif layer == 1:
            self.set_hsv_fill(109, 135, 186) # Onshape's green color

rgb = LayerColor(
    RGB_CHAIN_HEAD_PIN, 
    NUM_LEDS,  
    val_default = 150
    )

keyboard.extensions.append(rgb)

class ColorLayers(Layers):
    def activate_color_layer(self, keyboard, layer, idx=None):
        super().activate_layer(keyboard, layer, idx)
        rgb.set_light_layer(layer)
    
    def deactivate_color_layer(self, keyboard, layer):
        super().deactivate_layer(keyboard, layer)
        rgb.set_light_layer(keyboard.active_layers[0])

keyboard.modules.append(ColorLayers())

rgb_layers = ColorLayers(Layers())

# Macro to open whatever programs you might need for work, currently setup for a current fallout workflow
WORK_SETUP_INIT = KC.MACRO(
    # Web Tabs
    Press(KC.LGUI),
    Press(KC.S),
    Release(KC.LGUI),
    Release(KC.S),
    Tap("Firefox"),
    Tap(KC.ENTER),
    Delay(500), # Adjust if starts skipping steps?
    Tap(KC.LCTL(KC.T)),
    Tap("cvilleschools.onshape.com"),
    Tap(KC.ENTER),
    Delay(100),
    Tap(KC.LCTL(KC.T)),
    Tap("mail.google.com"),
    Tap(KC.ENTER),
    Delay(100),
    Tap(KC.LCTL(KC.T)),
    Tap("fallout.hackclub.com"),
    Tap(KC.ENTER),
    Delay(100),
     

    # PCB Design Software
    Tap(KC.ENTER),
    Press(KC.LGUI),
    Press(KC.S),
    Release(KC.LGUI),
    Release(KC.S),
    Tap("EasyEDA Pro"),
    Tap(KC.ENTER),
    
    # Software, IDE's etc.
    Press(KC.LGUI),
    Press(KC.S),
    Release(KC.LGUI),
    Release(KC.S),
    Tap("Visual Studio Code")
    )

DEFAULT_SETUP_INIT = KC.MACRO(
    Press(KC.LGUI),
    Press(KC.S),
    Release(KC.LGUI),
    Release(KC.S),
    Tap("Google Chrome"), # Settings need to be set to ensure that will actually load into a browser w/ search bar open at start
    Tap(KC.ENTER),
    Delay(500),
    Tap("https://www.youtube.com/watch?v=2qBlE2-WL60"), # Placeholder, albeit might forget to tell friends, convieniently ad-free. Can be replaced w/ cute cat vids link
    Tap(KC.ENTER)
)

# RGB Color Layer Control Macros
LAYER_INCREMENT = KC.MACRO(
    rgb_layers.deactivate_color_layer(keyboard.active_layers[0]),
    KC.TG(keyboard.active_layers[0] + 1),
    rgb_layers.activate_color_layer(keyboard.active_layers[0] + 1)
)

LAYER_DECREMENT = KC.MACRO(
    rgb_layers.deactivate_color_layer(keyboard.active_layers[0]),
    KC.TG(keyboard.active_layers[0] - 1),
    rgb_layers.activate_color_layer(keyboard.active_layers[0] - 1)
)

# Microphone code sadly disabled until next iteration, because currently I don't think circuitpython can output usb audio to Windows
"""
def activate_microphone():
    # Insert  circuitpython interaction code for mic
    mic = pio_i2s.I2S()
"""

# Button configs, KC.NO s are because of hexagon layout, t = top, b = bottom, l/m/r indicates left/middle/right
# DEFAULT LAYER
button_tl_zero = KC.LEFT
button_tm_zero = KC.UP
button_tr_zero = KC.RIGHT
button_ml_zero = KC.LCTL(KC.LSHIFT(KC.LEFT))
button_m_zero = KC.TD(KC.RGB_MOD, LAYER_INCREMENT)
button_mr_zero = KC.LCTL(KC.LSHIFT(KC.LEFT))
button_bm_zero = KC.DOWN

# ONSHAPE LAYER
# Onshape custom and default commands 
button_tl_one = KC.LSHIFT(KC.A) # Rebound to central point arc
button_tm_one = KC.LSHIFT(KC.ENTER) # End current mate and start new one
button_tr_one = KC.LCTL(KC.LSHIFT(KC.H)) # H for Hexagon, rebound to polygon tool
button_ml_one = KC.LCTL(KC.LSHIFT(KC.L)) # Rebound to slot tool
button_m_one = KC.TD(LAYER_DECREMENT, DEFAULT_SETUP_INIT, WORK_SETUP_INIT)
button_mr_one = KC.LSHIFT(KC.M) # Rebound to mirror
button_bm_one = KC.LCTRL(KC.LSHIFT(KC.Y)) # Rebound to symmetric

keyboard.keymap = [
    # Default Layer (0)
    [   
        button_tl_zero, button_tm_zero, button_tr_zero,
        button_ml_zero, button_m_zero, button_mr_zero,
        KC.NO, button_bm_zero, KC.NO
    ],
    # Onshape Layer (1)
    [
        button_tl_one, button_tm_one, button_tr_one,
        button_ml_one, button_m_one, button_mr_one,
        KC.NO, button_bm_one,KC.NO
    ]
]

if __name__ == '__main__':
    keyboard.go()

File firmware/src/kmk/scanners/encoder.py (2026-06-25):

import firmware.src.kmk.scanners.keypad as keypad
import rotaryio

from kmk.scanners import Scanner


class RotaryioEncoder(Scanner):
    def __init__(self, pin_a, pin_b, divisor=4):
        self.encoder = rotaryio.IncrementalEncoder(pin_a, pin_b, divisor)
        self.position = 0
        self._pressed = False
        self._queue = []

    @property
    def key_count(self):
        return 2

    def scan_for_changes(self):
        position = self.encoder.position

        if position != self.position:
            self._queue.append(position - self.position)
            self.position = position

        if not self._queue:
            return

        key_number = self.offset
        if self._queue[0] > 0:
            key_number += 1

        if self._pressed:
            self._queue[0] -= 1 if self._queue[0] > 0 else -1

            if self._queue[0] == 0:
                self._queue.pop(0)

            self._pressed = False

        else:
            self._pressed = True

        return keypad.Event(key_number, self._pressed)

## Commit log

2026-06-20 Added BOM
    [bom.csv]
2026-06-20 Corrected PCB naming in BOM
    [bom.csv]
2026-06-20 Corrected PCB naming in BOM, added 3d models, updated README.md
2026-06-22 Added more images of wiring schematic, pcb, etc. into readme
2026-06-22 Added more angles of CAD into readme
2026-06-23 Added pricing
    [bom.csv]
2026-06-24 Added costs for owned materials
    [bom.csv]
2026-06-24 Seeing if commas are breaking bom formatting
    [bom.csv]
2026-06-24 Removed commas in bom
    [bom.csv]
2026-06-24 Added commas between columns
    [bom.csv]
2026-06-24 Fixed row two issue
    [bom.csv]
2026-06-24 Fixed final column comma issue
    [bom.csv]
2026-06-24 comma issue
    [bom.csv]
2026-06-24 missed misplaced commas in bom
    [bom.csv]
2026-06-24 Restoring accidentally deleted lines
    [bom.csv]
2026-06-24 missed a comma
    [bom.csv]
2026-06-24 missed another comma on l16
    [bom.csv]
2026-06-24 last comma fix
    [bom.csv]
2026-06-24 Added BOM in .csv format to readme, and added a redundant onshape link
2026-06-24 Added PCB order
2026-06-25 Added case step files
    [case_body.step, case_top.step, pcb_to_screw_spacer.step]
2026-06-26 Added case step files Added soldering stuff to BOM (assuming soldering in well-ventilated space lol).. Also, added more links in the setup guide
    [bom.csv, pick_and_place_macragon.xlsx]
2026-06-26 Added soldering stuff to BOM, and more file/website links to readme setup guide
2026-06-26 Changed grammar in readme and updated readme markdown bom table
2026-06-26 Fixed numbers in screw row of BOM being enlarged (???)
    [bom.csv]
2026-06-26 Replaced macragon wiring schematic to remove highlighted box and to clean up boxes
2026-06-26 Fixing BOM commas again
    [bom.csv]
2026-06-26 Fixed BOM based on suggestions (removing C1/R1, etc. designations)
    [bom.csv]
2026-06-26 Moving pcb to bottom of BOM
    [bom.csv]
2026-06-26 Updating bom in readme
2026-06-27 fixing step files so part studio and assembly are both one step file
    [macragon_case_part_studio.step]
2026-06-27 Added macragon assembly and part studio as individual step files each instead of zip files. Also updated BOM and README to include filament instead of 3D printer
2026-06-28 Added links for m3 hex nuts and solder
    [bom.csv]
2026-06-28 Updated Readme BOM
